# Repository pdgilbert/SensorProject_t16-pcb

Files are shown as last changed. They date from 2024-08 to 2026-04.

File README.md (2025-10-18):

# SensorProject_t16-pcb
Connect multiple temperature sensors to an analog digital converter.

##  Status: Working Prototype.

## Summary

Kicad PCB design to connect multiple (up to 16) thermistor temperature sensors to an ads1115 with I2C
output to connect to an MCU. Connectors are  2-pin JST XH_B2B-XH-A, as commonly used on NTC 10K 3950 sensors.
These sensors are inexpensive and easily available in lengths up to 3m. 
Measurements are broadcast with LoRa.

Software for this hardware is in repository https://github.com/pdgilbert/SensorProject_t16.
The overall project, recording station, etc., 
is described in repository https://github.com/pdgilbert/SensorProject.

The `.png` and `jpg` files are produced from kicad in the `3D Viewer`  with `File > Export Current View as ...`.
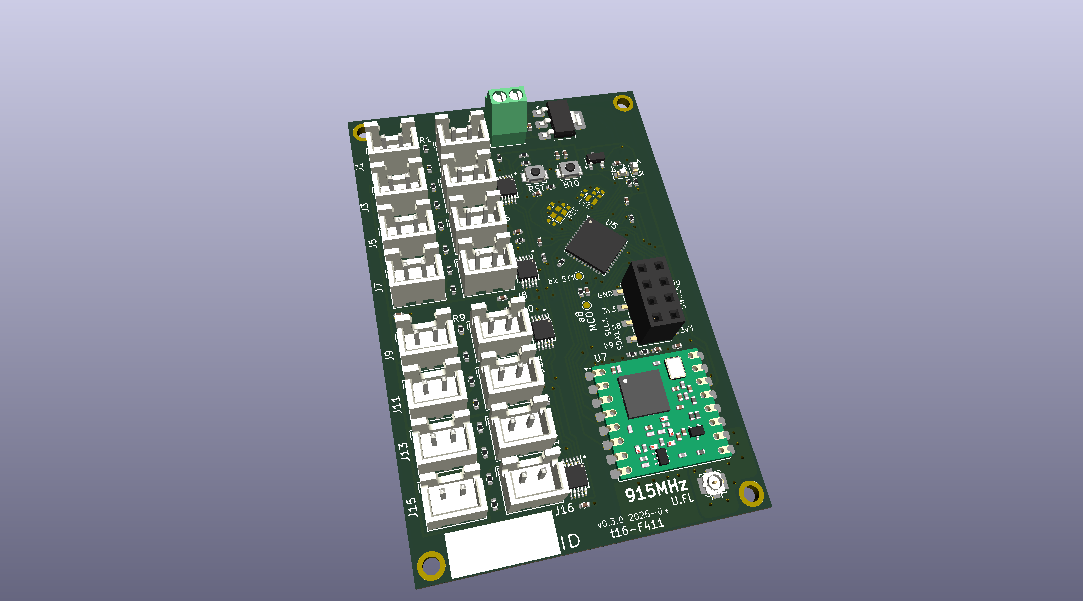
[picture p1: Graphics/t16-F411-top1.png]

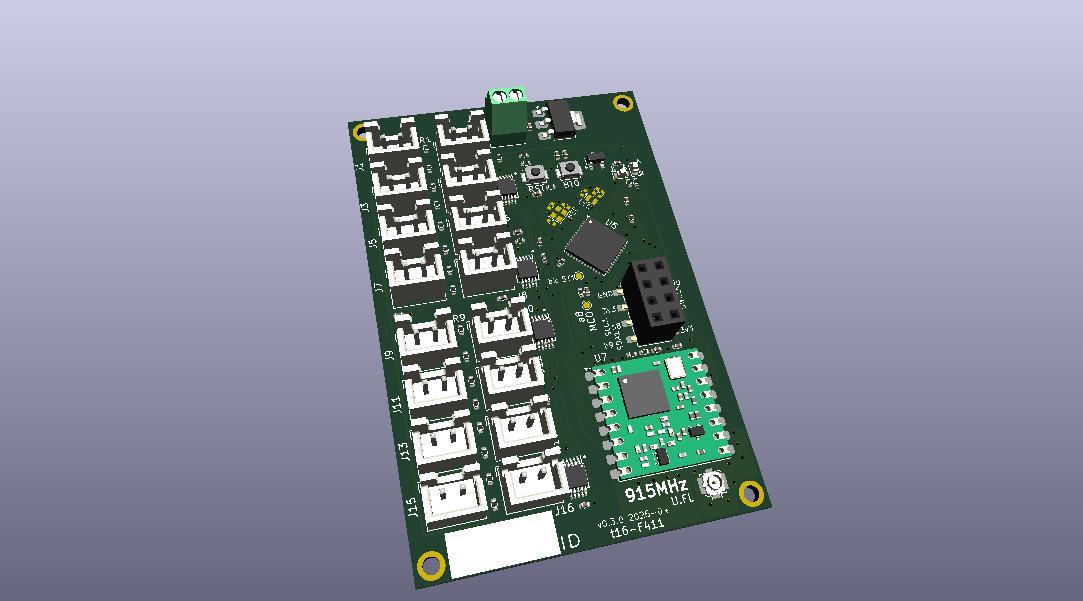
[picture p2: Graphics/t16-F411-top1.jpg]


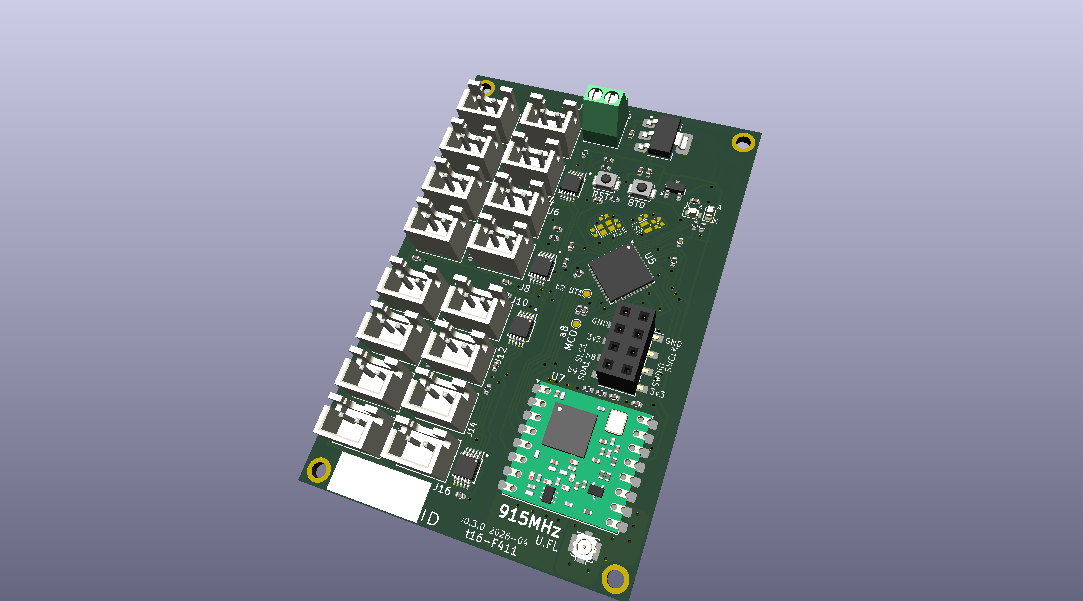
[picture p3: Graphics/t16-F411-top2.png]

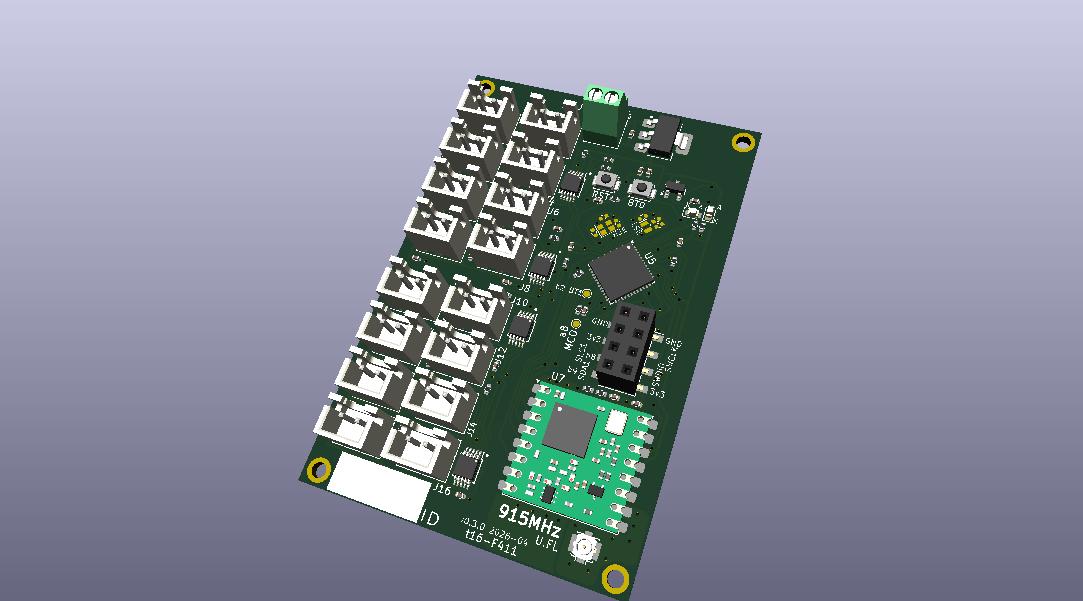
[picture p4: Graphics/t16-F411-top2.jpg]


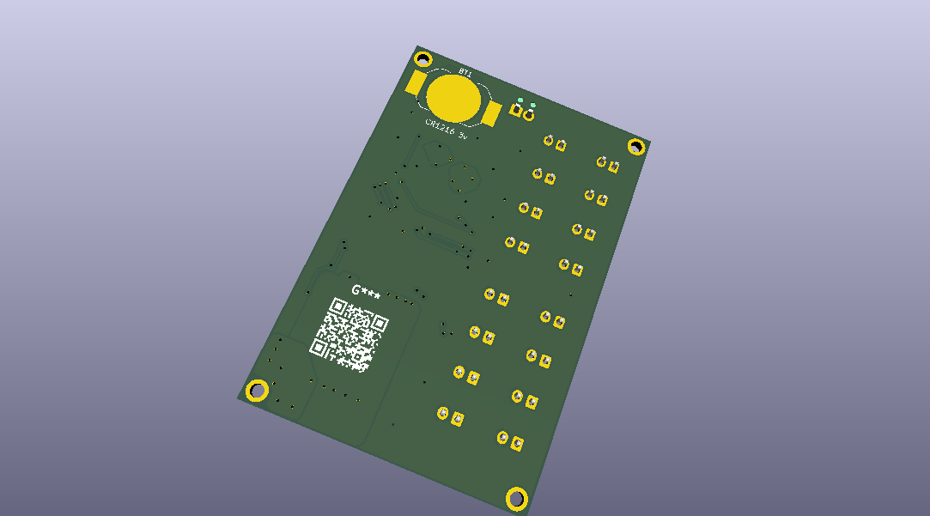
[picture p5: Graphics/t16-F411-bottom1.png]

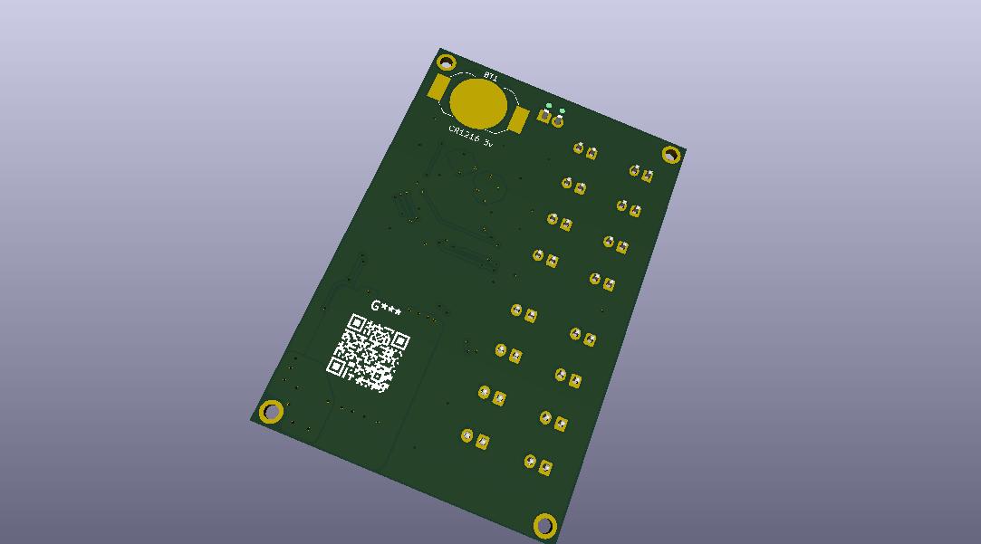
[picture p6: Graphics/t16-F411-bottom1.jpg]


See also file ProjectNotes.txt for additional hardware details.

## History

To see tags and tag messages use  git tag -n 

 - Version 0.2.2 2025-09 includes an stm32f411 MCU. It has an unshielded LoRa module RFM95W.
   It works with no necessary hardware adjustments. Two minor fixes to the BOM are added.
   (The HSE, LSE and RTC are still untested.)

 - Version 0.2.0 2025-05 includes an stm32f411 MCU. It has an unshielded LoRa module RFM95W.
   It needs some hardware re-adjustment to work.

 - Version 0.1.1 2025-01 has pull up resistors added but has not been manufactured/tested.

 - Version 0.1.0 2024-05 needs manual addition of pull up resistors on the I2C lines. 
   With this modification it works with `blackpill` `stm32f401` or `stm32f411` inserted.
   This versin has no LoRa module.

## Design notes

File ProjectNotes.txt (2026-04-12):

grep "/////////////// " ProjectNotes.txt   # for section index

////////////////////////////////////////////////////////////////////////////////
///////////////     General Notes
////////////////////////////////////////////////////////////////////////////////

(See also file `README.md`.)

The 16 JST 2-pin connectors are a size used by many NTC suppliers. 
The NTC sensors are easily available and inexpensive.

The PCB board is 48.1mm by 70.8mm (previously 48.11mm by 70.83mm), which fits (tightly) in a standard NA electric outlet hole. 
This allows for a standard outlet faceplate cover. The board needs to be supplied by low voltage (5v).
An outlet box is not a good option because of the number of sensor wires, but a low voltage single gang 
wall plate with no back, as often used for audio or TV cable, is a good option.

The mounting hole centers are 43.5mm apart in x direction and 66.5 mm in y direction.

In addition to the JST connectors on the analog digital converter (adc) and the LoRa module, the board has 
  - 4 pins on an 8 pin header to connect a ST-link programming dongle.
  - 4 pins on an 8 pin header to connect ssd display on I2C1.
  - a red led indicating when it is powered up.
  - a blue led on pin PC13 which can be programmed to turn on and off.
  - a 25 MHz crystal for the high speed external (HSE) oscillator. (still untested)
  - a 32.768 kHz crystal for the low speed external (LSE) oscillator. (still untested)
  - a coin cell battery holder to supply the real time clock (RTC). (still untested)
  
The HSE, LSE, and RTC are not used by current software but are on the board for future possibilities.
They can be marked do not populate (DNP) to reduce cost.

////////////////////////////////////////////////////////////////////////////////
///////////////            To Do
////////////////////////////////////////////////////////////////////////////////
- Report footprint BUG AMS1117 regulator tab should connect to output not gnd! Requires changing pin 4 GND -> VO
- The crystals/capacitors need testing and may need adjustment. 
- Consider STM32WLE5CCU6 version of MCU with built in LoRa (but need eh1 Rust crate).
    https://www.st.com/en/microcontrollers-microprocessors/stm32wl-series.html
- Consider different cheaper radio options?
- Need LoRa software and radio update.
- The radio needs more testing. 

- 5v J20 connector is a bit fragile. Consider something more robust.
- red led is still pretty bright.

- Consider power led blink off on reset?
- Consider reverse-polarity-protection
      https://electronics.stackexchange.com/questions/665044/which-reverse-polarity-protection-is-better-and-why  

- Need to check clock sensitivity to power suppy.
- Consider possible compensation in temperature calculation with low voltage supply?

-testing:
  - Check if RTC works.
  - Check what happens to RTC when VDD is gone and so NRST goes low.
  - Check HSE and LSE oscillating.

- learn spice.
  
//////////////////////// Sensitivity to Power Suppy

The regulator needs at least 4.3v supply on the J20 connector. Testing has been mostly done with a
5v suppy.  If a 3.2v battery is used to supply the regulator (instead of 5v) then the system boots
and the radio transmits, however the temperature readings are high by nearly 10C.

See below  `revision history and notes` for more details on temperature sensitivity to power suppy.

////////////////////////////////////////////////////////////////////////////////
///////////////            LSE and HSE oscillators
////////////////////////////////////////////////////////////////////////////////

Current software does not require RTC battery, LSE or HSE oscillators. 
LSE and HSE are experimentation for future possibilities.

Regarding Master Clock Output on pins see 
https://community.st.com/t5/stm32-mcus/how-can-i-output-a-clock-signal-to-the-stm32-s-mco-pin/ta-p/588222
and
https://aticleworld.com/stm32h573-mco-clock-output-configuration/

From the datasheet, for UFQFPN48 chip, MCO_1 is on pa8 pin 29. 
MCO_2 requires a 64 pin package to get pc9 so some diagnostics are not available.

///  See ProjectAlternateParts.txt re alternative parts and especially xtal calculations

////////////////////////////////////////////////////////////////////////////////
/////////////////////  RFM95  LoRa radio
////////////////////////////////////////////////////////////////////////////////

Reset pin has internal pull-up.  Do not hold low for long. Current code does not attempt reset.
See  https://www.mouser.ca/datasheet/2/975/1463993415RFM95_96_97_98W-1858106.pdf
"A manual reset of the RFM95/96/97/98(W) is possible even for applications in which VDD cannot
be physically disconnected. Pin 7 should be pulled low for a hundred microseconds, 
and then released. The user should then wait for 5 ms before using the chip."

////////////////////////////////////////////////////////////////////////////////
///////////////     alternate  parts
////////////////////////////////////////////////////////////////////////////////

- See also file ProjectAlternateParts.txt for (very disorganized) notes on alternate parts.

////////////////////////////////////////////////////////////////////////////////
///////////////     battery pad
////////////////////////////////////////////////////////////////////////////////

See https://electronics.stackexchange.com/questions/226967/coin-cell-battery-retainer-problems-and-best-practices
1. Use contact made for this purpose, eg Keystone.  This ... works and allows a lot of routing flexibility beneath the battery.
2. Use ENIG surface finish for the bottom pad.

////////////////////////////////////////////////////////////////////////////////
///////////////     tags and versions
////////////////////////////////////////////////////////////////////////////////

See README.md  History section.

To see tags and tag messages use  git tag -n 
 
////////////////////////////////////////////////////////////////////////////////
///////////////     revision history and notes
////////////////////////////////////////////////////////////////////////////////

///////////////  v0.2.2 2025-09 prototype notes

- includes an STM32F411CEU6 MCU. 
- has a LoRa module HopeRF  RFM95W-915S2  with no shield.
- has a U.FL (IPex 1) socket to attach antenna.

- status: prototype works with no hardware changes, but see below. 
          The necessary BOM changes as below are incorporated in the git version tagged `v0.2.2`.

- manufacturering errors/fixes/clarifications
   - Question re paste on battery pad. Should indicate no paste on battery pad, and ENIG. 
   - Fixed. BOM  had  Hong Cheng HC-PM254-5.0H-2x8PS which has 16 pins (8 pins per row, not 8 pins total)
      Should be Hong Cheng HC-PM254-5.0H-2x4PS-02A  https://www.lcsc.com/product-detail/C42163132.html
      Note also, footprint should work but could be improved to match recommended.
   - Done. Change the part# for UF.L. Footprint was for the gold part and silver was order.
     (The wrong footprint worked but engineering complained that the extra pad was not connecting.)
     The footpint for HRS part silver plated U.FL-R-SMT-1(60) is slightly different from 
     gold plated part U.FL-R-SMT-K(800). Gold has a 3rd ground connect pad opposite the signal pad.
     See  https://www.hirose.com/en/product/document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 
   - KF128-2.54-2P has no positioning pins but footprint has holes. 
     Yes, it is ok to ignore the positioning holes and solder as is.
   
- testing notes with v0.2.2. (Test files in crate SensorProject_t16  examples/ and src/bin/
    (5v supply actually shows 5.21v on measurement dongle and 5.14v on voltmeter.)
    - blink_default runs. Timer good on dongle and 5v supply. 
    - blink_hsi16   runs. Timer good on dongle and 5v supply.
    - blink_hse     fails. Software bug. Run time error `assertion failed: clk.raw() % FREQ == 0`.
    - text_i2c  runs (needs semihosting) using both 128x32 and 128x64 displays.
    - lora_spi_send runs on dongle and 5v. 5v supply draws 20 to 30 mA.

    - t16-f411 main bin  runs on dongle and 5v supply, with and without display. 
      With the display, the 5v supply draws 20 to 30 mA with about 140 mA spike on startup.
      Power usage is similiar without the display.
    - wire antenna on U.FL is as good as the spring coil antenna, possibly better.
    
    - measured temperature is sensitive to voltage supplied to the sensors. 
      At 30 mA the 3.3v AMS1117 regulator should be ok to about 40v supply, but the regulator
      might become noticably warm. Testing has mostly been done with 5v supplied to the AMS1117, 
      but 12v supply is also reported below.
      The AMS1117 needs dropout of 1v, so at least 4.3v supply to give 3.3v to the sensors. 
      The STlink dongle does not use the AMS1117. It supplies 3.3v directly, bypassing the AMS1117.
      If many sensors are connected then the STlink regulator may not supply proper voltage.
      Following testing was done with the equivalent of 4 sensors connected.
        J1 has NTC at room temperature (which changed during testing).
        J2 has  10K resistor connected, which should measure 25 C.
        J3 has  33K resistor connected, which should measure 0.2 C.
        J4 has 100K resistor connected, which should measure -19 C.
        J5 and others have nothing connected.

      It is also possible to power with a LFePo 3.2v battery connected directly to GND and 3v3,
      for example, using the STlink socket. Measurements below show how this affects the measurement.

      5v     XX< J1: 20.1 J2: 23.5 J3: -2.5 J4:-16.2   J5:-25.1  thru AMS1117
      STlink XX< J1: 20.7 J2: 23.5 J3: -2.5 J4:-16.2   J5:-25.1  direct  @3.2+v
      12v    XX< J1: 18.5 J2: 23.4 J3: -2.6 J4:-16.3   J5:-25.2  thru AMS1117
      LFePo  XX< J1: 21.1 J2: 24.8 J3:  0.5 J4:-13.8   J5:-22.4  direct  @3.2+v
      LFePo  XX< J1: 22.1 J2: 25.5 J3:  0.6 J4:-12.5   J5:-21.0  direct  @3.15v
      LFePo  XX< J1: 22.6 J2: 26.2 J3:  1.7 J4:-11.2   J5:-19.6  direct  @2.97v

      Note that the software calculation of the temperature from measured voltage can be improved,
      but does need to assume an adequate stable supply.

///////////////  v0.2.0 2025-05 prototype notes

- includes an STM32F411CEU6 MCU. 
- has a LoRa module HopeRF  RFM95W-915S2  with no shield.
- has a hole to solder on spring coil antenna.

- status: works to measure and transmit. I2c for ssd is on wrong pin, so no display. Tab on regulator is
wrong (on ground and should be on output voltage) and has to be cut.

- testing notes with v0.2.0. (Test files in crate SensorProject_t16  examples/ and src/bin/
    - blink[_hsi] runs.     0.02 A  with 5v input  ( 0.04A with st-link still attached but not powered)
    - blink_impl runs.      ditto
    - text_i2c   fails      init() error BusWriteError because sda1 mistakenly wired to pb6 on pin 42
    - lora_spi_send runs.   0.02 A  with 5v input  ( ditto )
    - measured temperature is sensitive to good supply voltage (see below).

- Temperature values for different power sources (testing with v0.2.0 2025-05):
    fixed resistors :                              J1: 10k  J2: 33k  J3: 100k    J4: sensor 
        should give temperature:                   J1: 25C  J2: 0.2C J3: -19C     J4: ~22-24C

    power by programming dongle                    J1: 26.9 J2:  2.7 J3:-10.1    J4: 24.5
    power by programming dongle                    J1: 25.4 J2:  0.3 J3:-12.8    J4: 23.0
    power by programming dongle                    J1: 25.9 J2:  1.2 J3:-11.8    J4: 23.6 

    power by 3.2v thru regulator                   J1: 43.2 J2: 27.7 J3: 19.5    J4: 41.8
    power by 3.?v thru 3v I2Cx                     J1: 28.5 J2:  5.2 J3: -7.1    J4: 26.8
    power by 3.0v (weak LiFePo bat) thru 3v I2Cx   J1: 31.3 J2:  9.5 J3: -2.1    J4: 29.8
    power by 3.7v (weak USB bat) thru regulator    J1: 23.6 J2: -2.3 J3:-16.0    J4: 21.8 but timing is fast

    power by 5v USB charger thru regulator         J1: 23.7 J2: -2.2 J3:-15.9    J4: 21.5 
    power by 5v USB charger thru regulator         J1: 23.6 J2: -2.3 J3:-16.0    J4: 21.7 
    power by 5v USB charger thru regulator         J1: 23.7 J2: -2.3 J3:-16.0    J4: 21.0 
    power by 5v USB charger thru regulator         J1: 23.7 J2: -2.3 J3:-16.0    J4: 21.6

    power by 5v wall supply thru regulator         J1: 23.7 J2: -2.3 J3:-16.0    J4: 19.3
    power by 5v wall supply thru regulator         J1: 23.7 J2: -2.3 J3:-16.0    J4: 19.3

- errors/fixes (Done indicates the change should be in the next release.):
  - Done (but then switched to smaller footprint). Get correct footprint L1 for MLZ1608N2R2LT000.
         (See also https://gitlab.com/kicad/libraries/kicad-footprint-generator/-/merge_requests/1797 )
  - Done. AMS1117 regulator tab should connect to output not gnd! BEWARE require symbol edit pin 4 GND -> VO
             and watch it does not reset as updating symbol may mess this up. REPORT SYMBOL BUG? maybe both ? and ?_tab2
  - Done. I2C2 is used for ads bus but is labelled 1 in schematics.
  - Done. I2C for ssd is mistakenly labelled scl2, sda2. Closer to I2C1, but still wrong.  
          v0.2.0 2025-0 has wrong pin for sda1. It has b6 on pin 42 but needs b9 (pin 46 UFQFPN48).
  - Done. consider labelling sda1 as pin b?, etc.
  - Done. pull-ups on ssd bus (mistakenly sda2 and scl2).
  - Done. label bt0 and nrst vs sw1 and sw2. And check they work.
  - Done. add label for battery type CR1216 3v
  - Done. switch antenna hole for U.FL-R-SMT-1 (ipex 1). 
          Added zone GND_ANT on RFM pin10 since it is closest to ant pin, but there is no documention about 
          which gnd pin to use, or even suggesting analog and digital grd parts of RFM are separated.
  - Done. label MCO as pin b? (MCO2 not possible with UFQFPN48 package).
  - Done. (See below.) check if it works with 3.2v through regulator.
  - Done. check in rfm95 doc https://cdn.sparkfun.com/assets/learn_tutorials/8/0/4/RFM95_96_97_98W.pdf
  - Done. cleanup and recheck BOM.
  - Done. check question about led orientatins. Add indicators.
          For BT1, no solder paste on the center big pad added to fab layer notes. 
  - Done. reduce led brightness. Changed MfgPart and adjusted resistors.
  - Done. Replaced ssd and st-link connections with 2x4 smt pinsocket. (stlink plug clearance for larger ssd. & low profile? 2x4 smt?)
  - Done. make boot1 pin 20 available to pull high. (Shared pin, if boot0 is high it is read at boot then available for other function?)
          (see notes https://community.st.com/t5/stm32-mcus-products/quadspi-and-boot1-with-stm32f446ret6/m-p/786873)
           https://deepbluembedded.com/stm32-boot-modes-stm32-boot0-boot1-pins/
  - Done. fab layer red led D1 indicates 2.65Vf. Should be 1.8Vf. (Blue is  2.65Vf.)
  - Done. make J18 (MCO) a test point pad rather than hole.

-improvements:
  - Done. Switch to smaller footprints for R, C, L, and leds.
  - Done. radio on same side as MCU.
  - Done. mv R23 and R25 to same side as MCU and radio and eliminate PTH in MCU area.

///////////////  version 0.1.1 2025-01 

- has pull up resistors added but was not manufactured/tested.

///////////////  v0.1.0 2024-05 

-This version has no LoRa module.

-It has pinsockets for a blackpill module.

-needs manual addition of pull up resistors on the I2C lines. 
   With this modification it works with `blackpill stm32f401` or `blackpill stm32f411` inserted.

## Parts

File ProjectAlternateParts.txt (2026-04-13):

To see the current specification the BOM .csv  can be imported to Excel or LibreOffice Calc or
displays nicely with
         column -s ";" -t <  outputs/BOM.csv | less -#2 -N -S
This assumes ; has been set as field separator. Otherwise "," in some fields causes problems
Helps to set range delimiter to -
( -N Don't use line numbers. -S Chop (truncate) long lines rather than wrapping. )

///////////////////// Caps  C_0402_1005Metric  Unpolarized capacitor

10pF C0G, NP0, +/- 0.1pF    TCC0402COG100K500AT
4pF C0G, NP0, +/- 0.1pF     GCM1555C1H4R0CA16D

100nF (= 0.1uF)             Yageo  CC0402KRX7R7BB104  CL05B104KO5NNNC

1uF                            CL05A105KP5NNNC
4.7uF                          CL05A475MQ5NRNC
10uF

///////////////////// Resisters   R_0402_1005Metric

10k 1%           CRCW040210K0FKED
715 1%           CRCW0402715RFKED
280 1%           RC0402FR-07280RL
0                RC0402FR-070RL
634  1%          ERJ2RKF6340X

///////////////////// Antenna

  See specific antenna notes further below.
  Also see 
    https://www.youtube.com/@Mobilefish  tutorial 47 and others
    https://www.youtube.com/watch?v=ZVo2RkBS14o  compares pcb and ceramic

    https://github.com/FabienFerrero/UCA_Board
    https://github.com/FabienFerrero/UCA21
    https://github.com/FabienFerrero/Antenna_Radiation_Measurement
    and other https://github.com/FabienFerrero/   repositories?

/////////////////////  Rome connectors
- J18, J19,  1x20_P2.54mm_Vertical      Female Header 2.54mm 180°Vertical Single row 20 Circuits(DIP)
     TXGA FFH25405-S20S1001K6K  or  JILN 22850120ANG1SYA01 or ...

- J20   1x02_P2.54mm_Horizontal   2 Screw horz TerminalBlock
  Phoenix_MPT-0,5-2-2.54_1x02_P2.54mm_Horizontal"  or Cixi Kefa Elec	KF128-2.54-2P	or ...
https://www.lcsc.com/datasheet/lcsc_datasheet_2303171000_Cixi-Kefa-Elec-KF128-2-54-2P_C474920.pdf

/////////////////////  Resistors, Capacitors and some connectors

- surface mount JST connectors not available in 2 connector. It is available for 3p and more.
  through hole is JST part XH_B2B-XH-A
  BM02B-XASS-TF(LF)(SN) is SMT but is XA connector, not sure it fits XH plugs
    probably not according to 
   https://www.mattmillman.com/info/crimpconnectors/common-jst-connector-types/#paxa

//// PCBWay  has supplied
Samsung	CL10A105KA8NNNC	Unpolarized capacitor	1µF
Samsung	CL10A475KP8NNNC	Unpolarized capacitor	4.7µF
Samsung	CL10B104KB8NNNC	Unpolarized capacitor	0.1µF
Samsung	CL10C100JB8NNNC	Unpolarized capacitor	10pF C0G, NP0, +/- 0.1pF
TDK Corp    CGA3E2C0G1H040CT0Y0N	Unpolarized capacitor	4pF C0G, NP0, +/- 0.1pF
Samsung	CL10B104KB8NNNC	Unpolarized capacitor	100nF

Panasonic	ERJ3EKF6980V	Resistor, US symbol	698
Yageo	RC0603FR-07274RL	Resistor, US symbol	274
Yageo	RC0603FR-070RL	Resistor, US symbol	0
Yageo	RC0603FR-07634RL	Resistor, US symbol	634  1%
Vishay	CRCW060310K0FKEA	Resistor, US symbol	10k 1%

JILN	22850104ANG1SYA01	PinSocket header 1x04  4P
Cixi Kefa Elec	KF128-2.54-2P	Generic screw terminal, 01x02
JILN	22850202ANG1SYA01	PinSocket header 2x02  4P
JST	B2B-XH-A	Connector JST_B2B-XH-A_1x02

/////////////////////  LoRa

NiceRF  LoRa1276-C1-915 is sheilded pin compatible replacement for RFM95W-915S2 (both using Semtech RF transceiver chip SX1276)
Also posibly hpdteks hpd13 module. 
See https://www.rocketscream.com/blog/2017/08/21/the-sx1276-modules-shootout-hoperfs-rfm95w-vs-nicerfs-lora1276-c1-vs-hpdteks-hpd13/

/////////////////////  Antenna

///////// socket
 U.FL=IPEX1.  IPEX4 is smaller.

///////// ceramic chip antennas 
Even thought the chip is small these seem to require a large area of the pcb for ground ...

 https://electronics.stackexchange.com/questions/243341/how-does-a-chip-antenna-work
 https://pcbartists.com/design/rf/chip-antenna-pcb-layout-bluetooth-wifi/

Specified subject to finding good footprint. Temp using coilcraft_MA5532-AE_RFID which is about right size:

//Other Antennas  

Unictron Technologies Corporation AA066   (digikey  H2U646MHLQ0200)
https://www.unictron.com/wireless-communications/wp-content/uploads/2021/04/AA066.pdf
$1.10  Gain 0.9dBi 2W  10x3.2x0.5 mm looks attractive but footprint landing 
pattern has restricted zone that gives a fairly big footprint (23x15mm).

Unictron Technologies Corporation   AA702 which is 915MHz, smaller and weaker,
 gain 0.8 2W  5.0 x 3.0 x 0.5 but digikey shows it H2U64U1H2C0200 but NOT 915MHx.
 and 
Unictron Technologies Corporation  H2U646MHLQ0200
https://www.digikey.com/en/products/detail/unictron-technologies-corporation/H2U646MHLQ0200/9921490
$1.10  Gain 0.9dBi 2W  10x3..2x0.5
have not found another source. Digikey has the evaluation board with 915!

Wurth 7488910915  https://www.digikey.com/en/products/detail/w%C3%BCrth-elektronik/7488910915/12726548
$1.24 Gain 0.5dBi

Taoglas ILA.01 https://www.digikey.com/en/products/detail/taoglas-limited/ILA-01/2332707
$14.17 Gain 1dBi max 5W
and also Taoglas DBP.915.V.A.30

Kyocera M620720
 https://www.kyocera-avx.com/product/ism-868-915-mhz-embedded-ceramic-antenna-m620720/
 https://www.digikey.ca/en/products/detail/kyocera-avx/M620720/6072490
$4.61  Gain 0.75 dBi  6.00 x 2.00 x 1.08  see datasheet p19 re glue
	
Johanson Technology Inc.
https://www.digikey.com/en/products/detail/johanson-technology-inc/0915AT43A0026001E/2137136
$1.54  Gain -1dBi 2 W
7x2mm chip but footprint with ground plan is 42x26mm
https://www.johansontechnology.com/products/antennas/rf-antennas/0915at43a0026001e/
https://www.johansontechnology.com/docs/4410/Antenna-0915AT43A0026001E.pdf

/////////////////////  regulator

https://www.alldatasheet.com/html-pdf/49118/ADMOS/AMS1117/519/4/AMS1117.html
http://www.advanced-monolithic.com/pdf/ds1117.pdf
https://electronics.stackexchange.com/questions/665044/which-reverse-polarity-protection-is-better-and-why

/////////////////////  leds
Resistance calculator:
https://www.digikey.cn/en/resources/conversion-calculators/conversion-calculator-led-series-resistor

blue very common: 2mA  2.65Vf  => 280 ohm resistor

blue:   Yongyu Photoelectric  yy0603bl-nn1s0-t2ar4  2.6~3.1v forward  0603 (1608 metric) 5ma 34~100mcd
                              yy0603bl-nz1s0-t2ar4 
                              yy0603bl-nn1s2-t2ar4            => 100 ohm resistor

blue:   Kingbright  APT1608LVBC/D        2mA  2.65Vf        => 280 ohm resistor
                or  APTD1608LVBC/D   APTD is slightly higher than APT and
                or  APTD1608LQBC/D   all have slightly different brightness.
                or  APHD1608LVBC/

red very common: 2mA  1.8Vf  => 715 ohm resistor

red:  (power led - consider Do Not Populate)
   Yongyu Photoelectric  yy0603re-nn1s0-t2ar4  1.8~2.3v forward  0603 (1608 metric) 5ma 34~100mcd
                         yy0603re-rn1s0-t2ar4 
                         yy0603re-rn2s1-t2ar4            => 400 ohm resistor
                         yy0603re-nn2s0-t2ar4 
                         yy0603re-nn3s0-t2ar4 

red:  Kingbright   APT1608LSECK/J3-PRV       2mA  1.8Vf     => 715 ohm resistor
            or  ...

/////////////////////  MCU 

Reference/Compare
   https://www.pcbway.com/project/shareproject/10_channel_NTC_thermistor_based_temperature_logger_b1c5cdfe.html
   https://stm32world.com/wiki/Black_Pill
   https://stm32-base.org/assets/pdf/boards/original-schematic-STM32F411CEU6_WeAct_Black_Pill_V2.0.pdf
   and   https://uglyduck.vajn.icu/STM32_Pills/BlackPill_STM32F411.pdf 
   and   https://www.pcbway.com/project/shareproject/STM32F401CCUx_core_board.html

   AN2606 Application note - STMicroelectronics STM32 microcontroller system memory boot mode Introduction 
   https://community.st.com/ysqtg83639/attachments/ysqtg83639/stm32-mcu-products-forum/28746/1/cd00167594-stm32-microcontroller-system-memory-boot-mode-stmicroelectroni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

   Reference Manual
   https://www.st.com/resource/en/reference_manual/rm0383-stm32f411xce-advanced-armbased-32bit-mcus-stmicroelectronics.pdf

   [not using STM32F401CCUx / UFQFPN48   x- temperture range and packaging
    STMicroelectronics Arm Cortex-M4 MCU, 256KB flash, 64KB RAM, 84 MHz, 1.7-3.6V, 36 GPIO, UFQFPN48

    The STM32F411 is preferred to STM32F401 because of the FPU, more memory, and also because the second generation (g2) 
    xtal drive allows more xtal possibilities and lower power consumption. Prices do not seem to be very different.
   ]

   Datasheet  STM32F411CEU6 / UFQFPN48
   https://www.st.com/resource/en/datasheet/stm32f411ce.pdf
   STMicroelectronics Arm Cortex-M4 MCU+FPU, 125 DMIPS, 512KB Flash, 128KB RAM, USB OTG FS, 11 TIMs, 1 ADC, 13 comm. interfaces
   C = 48/49 pins
   E = 512 Kbytes of flash memory
   U = UFQFPN
   6 = Industrial temperature range, - 40 to 85 °C
   TR = tape and reel / No character = tray or tube

//////////  MCU  xtals

!!! When considering external capacitors use COG NPO 1% types to minimize the impact of capacitance change over temperature.

Application Note  AN2867
Guidelines for oscillator design on STM8AF/AL/S and STM32 MCUs/MPUs
https://www.st.com/resource/en/application_note/cd00221665-oscillator-design-guide-for-stm8af-al-s-stm32-mcus-and-mpus-stmicroelectronics.pdf

(Summary at 
https://ecsxtal.com/considerations-when-designing-crystals-into-stm32-microcontrollers/  is helpful.)
https://community.nxp.com/t5/LPC-FAQs/How-to-calculate-the-value-of-crystal-load-capacitors/m-p/464589
https://electronics.stackexchange.com/questions/673522/how-do-you-design-a-crystal-oscillator-circuit-for-stm32f4-mcus

Notes from  AN2867

- p23 section 4  Guidelines to select a suitable crystal and external components

- From Fig 12, p23 discussing LSE but seems to apply to HSE too:
   High load-capacitance (such as 12.5 pF) requires more power to drive the oscillation. 
   Low power designs consequently needs relatively small load capacitance. 
   Big load capacitance resonators have a much smaller pullabilty.
   7pF in in the middle, the largest possilbe with low power drive and reasonably good pullabilty.

- p24 crystals with high ESR have longer startup time. Small crystals tend to have large ESR. 
  Without size constraints choose a crystal with the smallest possible ESR.
  In noisy environments (eg industrial applications) with no power constraints, choose crystals with high
  load capacitance. 

- p25 Table 5 for which MCUs have which LSE oscillators, and thus implication for which crystals work.

- p26 4.2  How to select an STM32-compatible crystal

- p31 which suggests cap values for various crystals  and tips in section 7!

- p10 For startup and stable oscillation of STM32 and STM8 products, the ratio between
the negative resistance of the loop and the crystal maximal equivalent series resistance
(ESR) is needed. It is recommended to have a ratio higher
than 5 for the HSE oscillators, and higher than 3 for the LSE oscillators.

- p13 the ratio between oscillator gain and oscillation loop critical gain cannot just (sic) exceed 1.
  For cristal specified  Gm_crit_max  check for oscillation loop critical crystal gain p13.

Regarding capacitors for crystals see application note AN2867
https://www.st.com/resource/en/application_note/cd00221665-oscillator-design-guide-for-stm8af-al-s-stm32-mcus-and-mpus-stmicroelectronics.pdf
and https://community.st.com/t5/stm32-mcus-products/stm32-f4-crystal-calculation-and-discrepancy-with-nucleo-boards/td-p/607114
and https://community.st.com/t5/stm32-mcus-products/calculate-external-capacitors-cl1-and-cl2-for-crystal-oscillator/td-p/620301

"It's better to measure freq on first PCB release/prototype sample via MCO pin (available on 
PA8 + others depends on device and package size). 
Measuring must be done by counter or by scope with averaging (or in counter mode) to avoid short 
term jitter. And then tune external capacitors accordingly to get nominal crystal frequency.
fmeas > fnom \u2026 increase external capacitors
fmeas < fnom \u2026 decrease external capacitors
"
And regarding measuring on PA8 see
https://community.st.com/t5/missing-articles/how-can-i-output-a-clock-signal-to-the-stm32-s-mco-pin/td-p/49583

Regarding setting RTC and LSE driver medium/low
https://blog.brendans-bits.com/posts/2024/setting-the-stm32-system-clock/

########## # python code to check crystal 

import math

def crit_margin(F, ESR, C0, CL, CS, gm, Vpp) :
   '''
   crit_margin(F, ESR, C0, CL, gm, Vpp)
     where
     F   in Hz is frequency.
     ESR in Ohms is equivalent series resistance of the crystal. 
     C0 in F is the crystal (shunt) capacitance.
     CS in F is the stray capacitance in the board, often assumed about 5 pF. Needs to be measured for best accuracy. 
     Note: If CL < CS then calculated external capacitors have negative value!
     CL in F is the load capacitance that the crystal is design to expect from the board (from CS and C1 and C2). 
     gm in A/V
     Vpp peak-to-peak voltage of oscillator. (which I think would not exceed Vss - Vdd)
   
   '''
   # C1 and C2 assumed equal and called C below. It is calculated from 
   #   CL = CS + C1*C2 / (C1 + C2)   # AN2867 p12
   #   CL = CS + C**2 / 2*C  = CS + C/2
   #    C = C1 = C2 = 2 * (CL - CS)
   C = 2 * (CL - CS)
   print("   Require external capacitors C1 = C2 = ", C)
   
   # (AN2867 p16 3.5.3) check ext resistor
   R_ext = 1.0 / (2.0 * math.pi * F * C)
   print("   Require external resistor R_ext = ", R_ext)
   
   # (AN2867 p14-16) need to check drive level   !!!!!
   
   gm_critical =   4 * (ESR + R_ext) * (2 * math.pi * F)**2 * (C0 + CL)**2  #p16
   gm_critical_no_R_ext = 4 * (ESR ) * (2 * math.pi * F)**2 * (C0 + CL)**2 
   
   gain_margin = gm / gm_critical   
   print("   gm_critical = ", gm_critical, " A/V; gain_margin =", gain_margin)
   
   gain_margin_no_R_ext = gm / gm_critical_no_R_ext   
   print("   gm_critical with no R_ext = ", gm_critical_no_R_ext, " A/V; gain_margin with no R_ext =", gain_margin_no_R_ext)
   
   # drive level (power dissipated by crystal  (AN2867 p14-16)
   Ctot =CL + (CS/2)
   DL = (ESR * (math.pi * F * Ctot)**2 * Vpp**2 ) /2   # No probe. Assuming Vpp =3.2v 
   print("   drive level = ", DL*10**6, " uW must not exceed manuf. spec.")
   
   print("\nNotes")
   print("R_ext is not recommended (=0) if the drive level is lower than specified by the manufacturer.")
   print("Otherwise, R_ext is needed.")
   print("gm should be (much) bigger than gm_critical, so gain margin >> 1")  #AN2867 p16
   print("Use COG NPO 1% capacitor types to minimize the impact of temperature.")
   
   if F > 10**7:  # HSE
      print("F4 HSE resonator needs frequency 4-26 MHz;  g_m(min) = 5mA/V;  G_m_crit_max = 1 mA/V (from AN2867 table 6, p29)")
       
   else:
      print("F411 (generation_2 LSE oscillator  from AN2867 table 5, p25)")
      print("     drive Low   g_m(min)=2.8 uA/V;  G_m_crit_max = 0.56 uA/V")
      print("     drive High  g_m(min)=7.5 uA/V;  G_m_crit_max = 1.5  uA/V")
   
   return()

########## #  check code's calculation
#  Example to check calculation against AN2867 p14. 

>>>crit_margin(F=8.0*10**6,  ESR=80,  C0=7.0*10**-12, CL=10.0*10**-12, CS= 5*10**-12,  gm=25*10**-3)
Require external capacitors C1 = C2 =  1e-11  # 10 pF
Use COG NPO 1% capacitor types to minimize the impact of temperature.
Require external resistor R_ext =  1989.436788648692   # 2K Ohms
gm_critical =  0.006044351471922944  A/V; gain_margin = 4.13609303101074
gm_critical with no R_ext =  0.00023366169984326241  A/V; gain_margin with no R_ext = 106.99228849558877

Notes
Use COG NPO 1% capacitor types to minimize the impact of temperature.
F411 (generation_2 LSE oscillator  from AN2867 table 5, p25)
     drive Low   g_m(min)=2.8 uA/V;  G_m_crit_max = 0.56 uA/V
     drive High  g_m(min)=7.5 uA/V;  G_m_crit_max = 1.5  uA/V

########## # 

//////////////////////////////////////////////////////// 
//////// Low speed oscillator (LSE)  F = 32.768   # kHz 
//////////////////////////////////////////////////////// 

////////  1.6 x 1.0mm

The sweet point for LSE crystals seems to be 7pF  from AN2867 Fig 12 p23). 
This can achieve low power drive requirement and low drift.

On Digikey it is *sometimes* possible to scroll down to substitues and find parametric substitues.
eg: https://www.digikey.ca/en/products/detail/ ... to Wurth 830066431
Otherwise select all atributes other than manufacture specific and "View Similar".

######  Micro Crystal 1.6 x 1.0mm
        CM9V-T1A-32.768KHZ-xPF-20PPM-TA-QC  (4, 6, and 7pF work for F411 in AN2867 p32 table 7. )
    C_0  1.4 pF;  ESR max 90kOhm on table but 75kOhm on datasheet;
C_L 4pF has gmcrit  0.4449 uA/V and works for F401 (g1) in AN2867 p31 table 7 but is not easily available. 
C_L 7pF has gmcrit  1.0768 uA/V and works for F411 (g2) in AN2867 p31 table 7 and is available.

######  Micro Crystal CM9V-T1A-32.768KHZ-7PF-20PPM-TA-QC
https://www.microcrystal.com/fileadmin/Media/Products/32kHz/Datasheet/CM9V-T1A.pdf
drive level 0.5uW max
gm_crit 1.078 uA/V  comes from AN2867 p31 table 7, p32, which also indicated the 7pF version of
this chip is good for F4_g2. The datasheet does not specify gm, or gm_crit, or gain_margin.

Assuming Vpp =3.2v  which is a max with 3.2v supply. (Would be better to measure with an oscillascope.
>>> crit_margin(F=32768.0,  ESR=70*10**3,  C0=1.4*10**-12, CL=7.0*10**-12, CS= 5*10**-12, gm=math.nan, Vpp=3.2) 

  Require external capacitors C1 = C2 =  4.000000000000001e-12   # 4 pF
  Require external resistor R_ext =  1214255.852446711           
  gm_critical =  1.536489948822002e-05  A/V; gain_margin = nan
  gm_critical with no R_ext =  8.374834049822095e-07  A/V; gain_margin with no R_ext = nan
  drive level =  0.3427794888872763  uW must not exceed manuf. spec.
( With Vpp = 3.2v the DL <  0.5uW manuf. spec, so R_ext should be =0.
  With Vpp = 5.0v the DL = 0.836 which exceeds the manuf. spec so an R_ext would be needed.)

Notes
R_ext is not recommended (=0) if the drive level is lower than specified by the manufacturer.
Otherwise, R_ext is needed.
gm should be (much) bigger than gm_critical, so gain margin >> 1
Use COG NPO 1% capacitor types to minimize the impact of temperature.
F411 (generation_2 LSE oscillator  from AN2867 table 5, p25)
     drive Low   g_m(min)=2.8 uA/V;  G_m_crit_max = 0.56 uA/V
     drive High  g_m(min)=7.5 uA/V;  G_m_crit_max = 1.5  uA/V

DID THIS WITH WRONG FREQ (25MHz)25.0*10**6  NOTE BIG DIFFERENCE IN R_ext
crit_margin(F=25.0*10**6,  ESR=70*10**3,  C0=1.4*10**-12, CL=7.0*10**-12, CS= 5*10**-12, gm=math.nan, Vpp=3.2) 
Require external capacitors C1 = C2 =  4.000000000000001e-12   # 4 pF
Require external resistor R_ext =  1591.5494309189532          # 1.6K
gm_critical =  0.49856303946047026  A/V; gain_margin = nan

4pF COG NPO 1% : 
eg Murata Electronics GJM0335C1E4R0WB01D  CAP CER 4PF 25V C0G/NP0 0201
0201 (0603 Metric)  0.024" L x 0.012" W (0.60mm x 0.30mm)

######  Wurth  830066431  IQXC-90   WE-XTAL QUARTZ CRYSTAL 32.7680 K   1.60mm x 1.00mm
https://www.we-online.com/components/products/datasheet/830066431.pdf
drive level 500nW max
>>> crit_margin(F=32768.0,  ESR=90*10**3,  C0=1.2*10**-12, CL=7.0*10**-12, CS= 5*10**-12, gm=math.nan, Vpp=3.2) 

######  TXC  9H03270102  1.6mm x 1mm   CL=6.0
drive level 0.1 uW typ 0.5 uW max
>>> crit_margin(F=32768.0,  ESR=70*10**3,  C0=1.3*10**-12, CL=6.0*10**-12, CS= 5*10**-12, gm=math.nan, Vpp=3.2) 

######  Epson  FC1610AN 32.7680KA-AG5   32.7680KHZ 7PF SMD  90 kOhms
https://support.epson.biz/td/api/doc_check.php?dl=brief_FC1610AN&lang=en
Not listed in AN2867 p31 table 7

######  NDK  narrowed down to NX1610SE 32.768 kHz  specification# STD-MUD-6
NDK crystals did not seem to be very readily available.
https://www.ndk.com/en/products/
https://www.ndk.com/en/products/lineup/crystal-unit/
https://www.ndk.com/images/products/catalog/crystal_e.pdf  
- AN2867 p31 table 7   NDK   NX1610SE 32.768 kHz EXS00A-MU01501 is good for F4.
                       Others, eg  -MU01500, are good for F4_g2, which includes F411 but not F401.  
   NX1610SE 32.768 kHz EXS00A-MU01501  specs from table 7: 
        ESR 60 kOhms max,  C_0 1.55pF,  C_L 6pF, g_mcrit 0.5799 uA/V
However what is available on NDK site
   https://www.ndk.com/en/products/lineup/crystal-unit/NX1610SE.html
  data sheet https://www.ndk.com/en/products/upload/lineup/pdf/NDKX01-00011_en.pdf
 NX1610SE 32.768 kHz  specification# STD-MUD-6  Load capacitance CL 6.0pF;  ESR Max. 60 kOhms ;

######  considering  ECS-.327-7-16-C-TR   ESR=90Kohms, CL=7pF, C0=1.3pF
Part Number/s	          STM32 Series
	    gm (uA/V)	Design Gm_crit-Max	Oscillator Margin	Actual gmcrit (µA/V)	Size	ESR k\u2126	Tolerance (ppm)	CL (pF)	C0	Operating Temp.	Rating	Data-sheet	Inventory
ECS-.327-7-16-C-TR	F4_g2 series / high
	7.50	1.5	7.13	1.0512	1.6 x 1.0mm	90	10	7.0	1.3	-40 ~ +85°C	-	https://ecsxtal.com/store/pdf/ECX-16.pdf	https://dilp.netcomponents.com/cgi-bin/ecsxtal.asp?=1&partnumber1=ECS-.327-7-16-C-TR

## from  ECS DESIGN TOOL https://ecsxtal.com/stm32-mcu-series-lse-32-768khz-crystal-selection-tool/
Part Number/s	           STM32 Series	        gm   Design Gm_ Oscill. Actual gmcrit 	Size	        ESR   Tolerance	CL 	C0	Operating 	Rating	Data-sheet	Inventory
                                               (uA/V) crit-Max	Margin	  (µA/V)	Size	       K Ohms  (ppm)	 pF 	 	 Temp.	        Rating	Data-sheet	Inventory
ECS-.327-4-16R-TR	F4_g1 series / Standard	2.80	0.56	9.10	0.3077487	1.6 x 1.0mm	60	20	4.0	1.5		        -	https://ecsxtal.com/store/pdf/ECX-16R.pdf	https://dilp.netcomponents.com/cgi-bin/ecsxtal.asp?=1&partnumber1=ECS-.327-4-16R-TR
ECS-.327-4-16R-TR	F4_g2 series / high	7.50	1.5	24.37	0.3077487	1.6 x 1.0mm	60	20	4.0	1.5		        -	https://ecsxtal.com/store/pdf/ECX-16R.pdf	https://dilp.netcomponents.com/cgi-bin/ecsxtal.asp?=1&partnumber1=ECS-.327-4-16R-TR
ECS-.327-7-16-C-TR	F4_g2 series / high	7.50	1.5	7.13	1.0512	        1.6 x 1.0mm	90	10	7.0	1.3	-40 ~ +85°C	-	https://ecsxtal.com/store/pdf/ECX-16.pdf	https://dilp.netcomponents.com/cgi-bin/ecsxtal.asp?=1&partnumber1=ECS-.327-7-16-C-TR
ECS-.327-6-16R-TR	F4_g2 series / high	7.50	1.5	13.11	0.5722	        1.6 x 1.0mm	60	20	6.0	1.5	-40 ~ +85°C	-	https://ecsxtal.com/store/pdf/ECX-16R.pdf	https://dilp.netcomponents.com/cgi-bin/ecsxtal.asp?=1&partnumber1=ECS-.327-6-16R-TR
ECS-.327-6-16-TR3	F4_g2 series / high	7.50	1.5	8.08	0.9284	        1.6 x 1.0mm	90	20	6.0	1.3	-40 ~ +85°C	-	https://ecsxtal.com/store/pdf/ECX-16.pdf	https://dilp.netcomponents.com/cgi-bin/ecsxtal.asp?=1&partnumber1=ECS-.327-6-16-TR3

Above results from ECS DESIGN TOOL for gm_critical and Oscill.Margin (=gain_margin) 
compare with no R_ext result below.  (Note uA/V above vs A/V below)

Notes from AN2867 table 5, p25)
     drive Low   g_m(min)=2.8 uA/V;  G_m_crit_max = 0.56 uA/V
     drive High  g_m(min)=7.5 uA/V;  G_m_crit_max = 1.5  uA/V

ECS-.327-4-16R-TR   ** Should have no  R_ext  **
>>> crit_margin(F=32768.0,  ESR=60*10**3,  C0=1.5*10**-12, CL=4.0*10**-12, CS= 0, gm=2.80*10**-6, Vpp=3.2)  # drive Low
  Require external capacitors C1 = C2 =  8e-12
  Require external resistor R_ext =  607127.9262233557
  gm_critical =  3.4217958694061296e-06  A/V; gain_margin = 0.8182837629311752  # gain margin SHOULD BE >> 1  !!
  gm_critical with no R_ext =  3.0774870020301075e-07  A/V; gain_margin with no R_ext = 9.098332497108649

ECS-.327-4-16R-TR    F4_g2 series / high    ** probably  no  R_ext  **
>>> crit_margin(F=32768.0,  ESR=60*10**3,  C0=1.5*10**-12, CL=4.0*10**-12, CS= 0, gm=7.50**-6, Vpp=3.2) # drive High
  Require external capacitors C1 = C2 =  8e-12
  Require external resistor R_ext =  607127.9262233557
  gm_critical =  3.4217958694061296e-06  A/V; gain_margin = 1.6420195438791367  # gain margin ok but not big
  gm_critical with no R_ext =  3.0774870020301075e-07  A/V; gain_margin with no R_ext = 18.257284885438484

ECS-.327-4-16R-TR    F4_g2 series / low   ** with low setting gain margin is good even with R_ext **
>>> crit_margin(F=32768.0,  ESR=60*10**3,  C0=1.5*10**-12, CL=4.0*10**-12, CS= 0, gm=2.80**-6, Vpp=3.2)   # drive Low
  Require external capacitors C1 = C2 =  8e-12
  Require external resistor R_ext =  607127.9262233557
  gm_critical =  3.4217958694061296e-06  A/V; gain_margin = 606.4537896301986
  gm_critical with no R_ext =  3.0774870020301075e-07  A/V; gain_margin with no R_ext = 6743.03765043816

//////////////////////////////////////////////////////// 
//////// High speed oscillator (HSE)  F = 25.0 *10**6  Hz  (25MHz)    4-pin, gnd on 2 & 4   2.0 x 1.6mm or 1.60 x 1.20mm footprint
//////////////////////////////////////////////////////// 

######   Epson  FA-128 25.0000MF20X-K0   2.0 x 1.6mm   10pf
https://support.epson.biz/td/api/doc_check.php?dl=brief_FA-128&lang=en
>>>crit_margin(F=25.0*10**6,  ESR=80,  C0=math.nan, CL=10.0*10**-12, CS= 5*10**-12, gm=math.nan, Vpp=3.2)
Require external capacitors C1 = C2 =  1e-11        # 10pF
Require external resistor R_ext =  636.6197723675814
gm_critical =  nan  A/V; gain_margin = nan
gm_critical with no R_ext =  nan  A/V; gain_margin with no R_ext = nan

Notes
Use COG NPO 1% capacitor types to minimize the impact of temperature.
F4 HSE resonator needs frequency 4-26 MHz;  g_m(min) = 5mA/V;  G_m_crit_max = 1 mA/V (from AN2867 table 6, p29)
()

###### look for SJK  q-crystal.com  referenced in 2.0 x 1.6mm footprint
https://q-crystal.com/home/index/product/eng/MHz-Crystal/f_eng/Crystal-Resonator-List.html

Shenzhen SCTF Electronics	SX1B25.000F0810F30	(25 days digi.ca  )
25 MHz ±10ppm Crystal 8pF 80 Ohms 4-SMD, No Lead   2.0 x 1.6mm 
https://www.sctf-crystal.com/data/upload/admin/20240930/1X-Series-2024-09-30.pdf
CL= 6-20 pF ;  C0=3pF max ; gm=    drive level 10uW typ 100uW max ;
>>>crit_margin(F=25.0*10**6,  ESR=80,  C0=3.0*10**-12, CL=8.0*10**-12, CS= 5*10**-12, gm=math.nan, Vpp=3.2)
Require external capacitors C1 = C2 =  6e-12                      # 6pF
Require external resistor R_ext =  1061.032953945969              # 1.1 K
gm_critical =  0.013626468075504283  A/V; gain_margin = nan
gm_critical with no R_ext =  0.0009553777060254499  A/V; gain_margin with no R_ext = nan

Notes
Use COG NPO 1% capacitor types to minimize the impact of temperature.
F4 HSE resonator needs frequency 4-26 MHz;  g_m(min) = 5mA/V;  G_m_crit_max = 1 mA/V (from AN2867 table 6, p29)

######      KKST 25.000 on blackpill. Cannot find manufactureer.

######   ECS Inc International    2.0 x 1.6mm
#Part Number/s	     Frequency  Series  gm      Gm_crit-Max   Oscillator gmcrit  Size (mm)   ESR   Tol.	 STAB.  CL     C0   Op. Temp	Rating	Data-sheet	Inventory
#                      (MHz)            (mA/V)      (mA/V)       Margin   (mA/V)                   (ppm)  (ppm) (pF)   (pF)
#ECS-250-8-37B2-RWY-TR	25.00	STM32F4	5.00	    1.00	 8.37	 0.597	  2.0 x 1.6   50   15      15	 8     3    -30/85C	-	https://ecsxtal.com/store/pdf/ECX-1637B2.pdf

>>>crit_margin(F=25.0*10**6,  ESR=50,  C0=3.0*10**-12, CL=8.0*10**-12, CS= 5*10**-12, gm=5.0*10**-3, Vpp=3.2)
Require external capacitors C1 = C2 =  6e-12                                    # 6pF
Require external resistor R_ext =  1061.032953945969                            # 1.1 K
gm_critical =  0.01326820143574474  A/V; gain_margin = 0.3768408268606718
gm_critical with no R_ext =  0.0005971110662659061  A/V; gain_margin with no R_ext = 8.373651540689075  !! this is value that compares with manuf. spec above

Notes
Use COG NPO 1% capacitor types to minimize the impact of temperature.
F4 HSE resonator needs frequency 4-26 MHz;  g_m(min) = 5mA/V;  G_m_crit_max = 1 mA/V (from AN2867 table 6, p29)

######   Wurth  IQXC-26  830081609    1.60 x 1.20mm   CHECK FOOTPRINT
 https://www.we-online.com/components/products/datasheet/830081609.pdf
drive level 100uW max     ESR=150max on datasheet, 200 on Digikey
>>> crit_margin(F=25.0*10**6,  ESR=150,  C0=3*10**-12, CL=8.0*10**-12, CS= 5*10**-12, gm=math.nan, Vpp=3.2)

DOES THIS MAKE SENSE??

F4 HSE resonator needs frequency 4-26 MHz;  g_m(min)=5;  G_m_crit_max = 1
Require external capacitors C1 = C2 =  6e-12                                       # 6pF
Require external resistor R_ext =  1061.032953945969                               # 1.1 K
gm_critical =  0.014462423568276551  A/V; gain_margin = nan

Notes
Use COG NPO 1% capacitor types to minimize the impact of temperature.
F4 HSE resonator needs frequency 4-26 MHz;  g_m(min) = 5mA/V;  G_m_crit_max = 1 mA/V (from AN2867 table 6, p29)
F411  drive Low   g_m(min)=2.8 uA/V;  G_m_crit_max = 0.56 uA/V (from AN2867 table 5, p25)
F411  drive High  g_m(min)=7.5 uA/V;  G_m_crit_max = 1.5  uA/V (from AN2867 table 5, p25)

######   IQD Frequency Products   LFXTAL081609    1.60 x 1.20mm
https://www.iqdfrequencyproducts.com/products/datasheets/LFXTAL081609.pdf
 ESR=150 on digikey  200max on datasheet;  drive level  100uW max
>>> crit_margin(F=25.0*10**6,  ESR=150,  C0=7*10**-12, CL=8.0*10**-12, CS= 5*10**-12, gm=math.nan, Vpp=3.2)

Require external capacitors C1 = C2 =  6e-12                                      # 6pF
Require external resistor R_ext =  1061.032953945969                              # 1.1 K
gm_critical =  0.026892936387291105  A/V; gain_margin = nan

Notes
Use COG NPO 1% capacitor types to minimize the impact of temperature.
F4 HSE resonator needs frequency 4-26 MHz;  g_m(min) = 5mA/V;  G_m_crit_max = 1 mA/V (from AN2867 table 6, p29)
F411  drive Low   g_m(min)=2.8 uA/V;  G_m_crit_max = 0.56 uA/V (from AN2867 table 5, p25)
F411  drive High  g_m(min)=7.5 uA/V;  G_m_crit_max = 1.5  uA/V (from AN2867 table 5, p25)

######   ITS Frequency Controls
https://www.iqdfrequencyproducts.com/products/datasheets/LFXTAL081609.pdf

######      25 MHz  NDK_NX1612SA     

########## IoT crystals

# Abracon  https://abracon.com/news/how-critical-is-gm-critical claims much better performance 
with tecknolegy not subject to this calculation (if I understand correctly, which is unlikely)

# Abracon   ABM12W at 25 MHz
crit_margin(F=25.0*10**6,  ESR=80,  C0=2.0*10**-12, CL=4.0*10**-12, gm=5.68*10**-3, Vpp=3.2)
gm_critical =  0.0002842446067513735  A/V; gain_margin = 19.98278899612773
that is gm_critical =  0.284 mA/V but their table shows 5.68  mA/V
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

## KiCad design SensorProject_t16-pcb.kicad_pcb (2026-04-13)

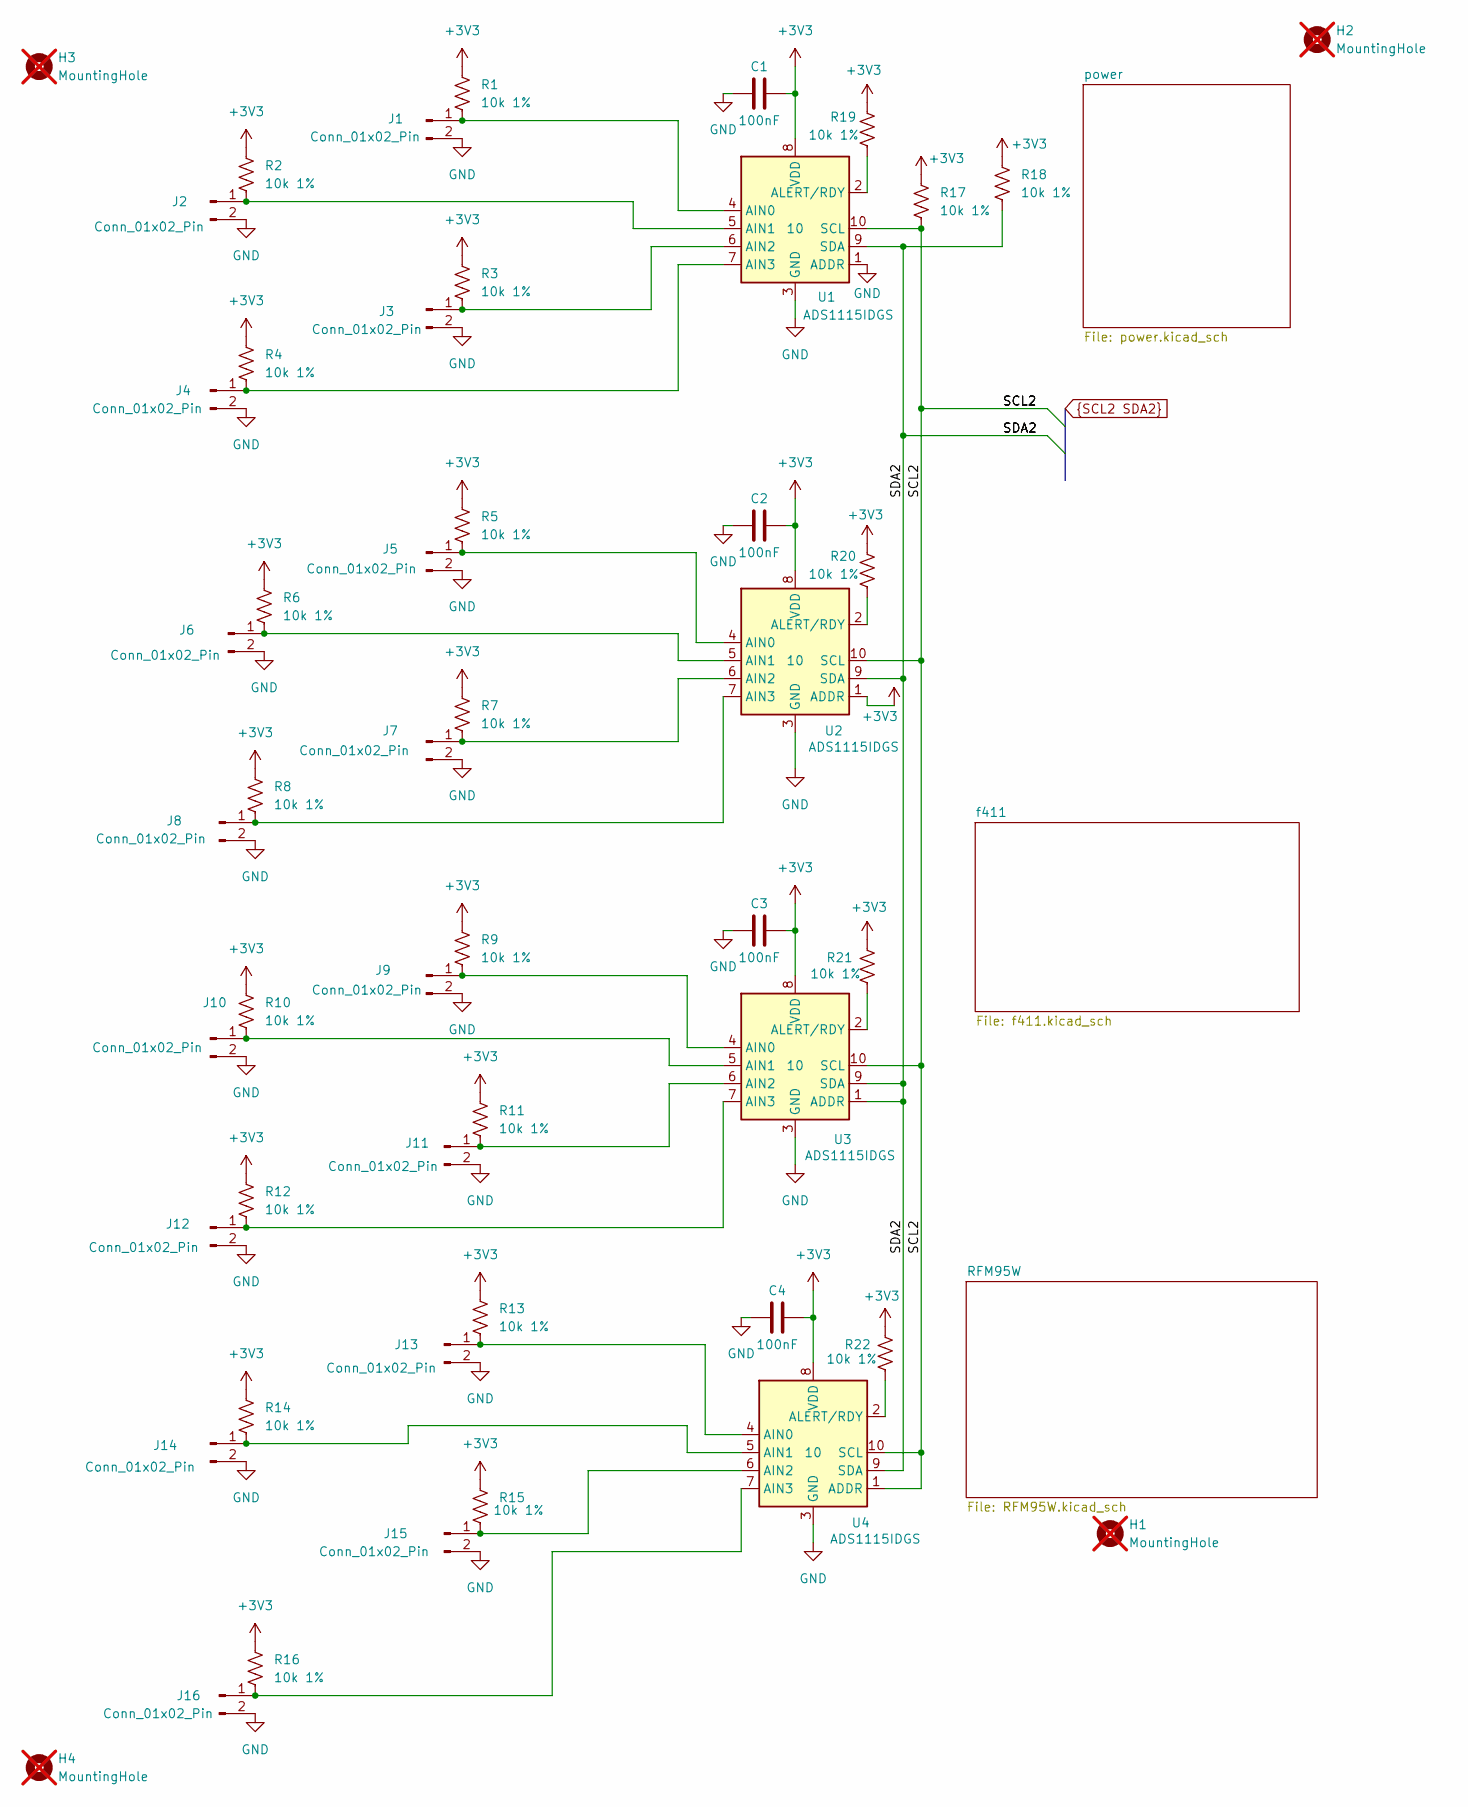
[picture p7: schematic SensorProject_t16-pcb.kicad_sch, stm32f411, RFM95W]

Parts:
C1, C2, C3, C4: 100nF; C_0402_1005Metric
H1, H2, H3, H4: MountingHole; MountingHole_2.2mm_M2_ISO7380_Pad; not fitted
J1, J2, J3, J4, J5, J6, J7, J8, J9, J10, J11, J12, J13, J14, J15, J16: Conn_01x02_Pin; JST_XH_B2B-XH-A_1x02_P2.50mm_Vertical; MfgPart B2B-XH-A
R1, R2, R3, R4, R5, R6, R7, R8, R9, R10, R11, R12, R13, R14, R15, R16, R17, R18, R19, R20, R21, R22: 10k 1%; R_0402_1005Metric
U1, U2, U3, U4: ADS1115IDGS; TSSOP-10_3x3mm_P0.5mm; MfgPart ADS1115IDGS

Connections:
+3V3: C1.1, C2.1, C3.1, C4.1, R1.1, R2.1, R3.1, R4.1, R5.1, R6.1, R7.1, R8.1, R9.1, R10.1, R11.1, R12.1, R13.1, R14.1, R15.1, R16.1, R17.1, R18.1, R19.1, R20.1, R21.1, R22.1, U1.8 (VDD), U2.1 (ADDR), U2.8 (VDD), U3.8 (VDD), U4.8 (VDD); also elsewhere on the board
GND: C1.2, C2.2, C3.2, C4.2, J1.2, J2.2, J3.2, J4.2, J5.2, J6.2, J7.2, J8.2, J9.2, J10.2, J11.2, J12.2, J13.2, J14.2, J15.2, J16.2, U1.1 (ADDR), U1.3 (GND), U2.3 (GND), U3.3 (GND), U4.3 (GND); also elsewhere on the board
unnamed: J1.1, R1.2, U1.4 (AIN0)
unnamed: J2.1, R2.2, U1.5 (AIN1)
unnamed: J3.1, R3.2, U1.6 (AIN2)
unnamed: J4.1, R4.2, U1.7 (AIN3)
unnamed: J5.1, R5.2, U2.4 (AIN0)
unnamed: J6.1, R6.2, U2.5 (AIN1)
unnamed: J7.1, R7.2, U2.6 (AIN2)
unnamed: J8.1, R8.2, U2.7 (AIN3)
unnamed: J9.1, R9.2, U3.4 (AIN0)
unnamed: J10.1, R10.2, U3.5 (AIN1)
unnamed: J11.1, R11.2, U3.6 (AIN2)
unnamed: J12.1, R12.2, U3.7 (AIN3)
unnamed: J13.1, R13.2, U4.4 (AIN0)
unnamed: J14.1, R14.2, U4.5 (AIN1)
unnamed: J15.1, R15.2, U4.6 (AIN2)
unnamed: J16.1, R16.2, U4.7 (AIN3)
unnamed: R19.2, U1.2 (ALERT/RDY)
unnamed: R20.2, U2.2 (ALERT/RDY)
unnamed: R21.2, U3.2 (ALERT/RDY)
unnamed: R22.2, U4.2 (ALERT/RDY)
SCL2: R17.2, U1.10 (SCL), U2.10 (SCL), U3.10 (SCL), U4.1 (ADDR), U4.10 (SCL); also elsewhere on the board
SDA2: R18.2, U1.9 (SDA), U2.9 (SDA), U3.1 (ADDR), U3.9 (SDA), U4.9 (SDA); also elsewhere on the board

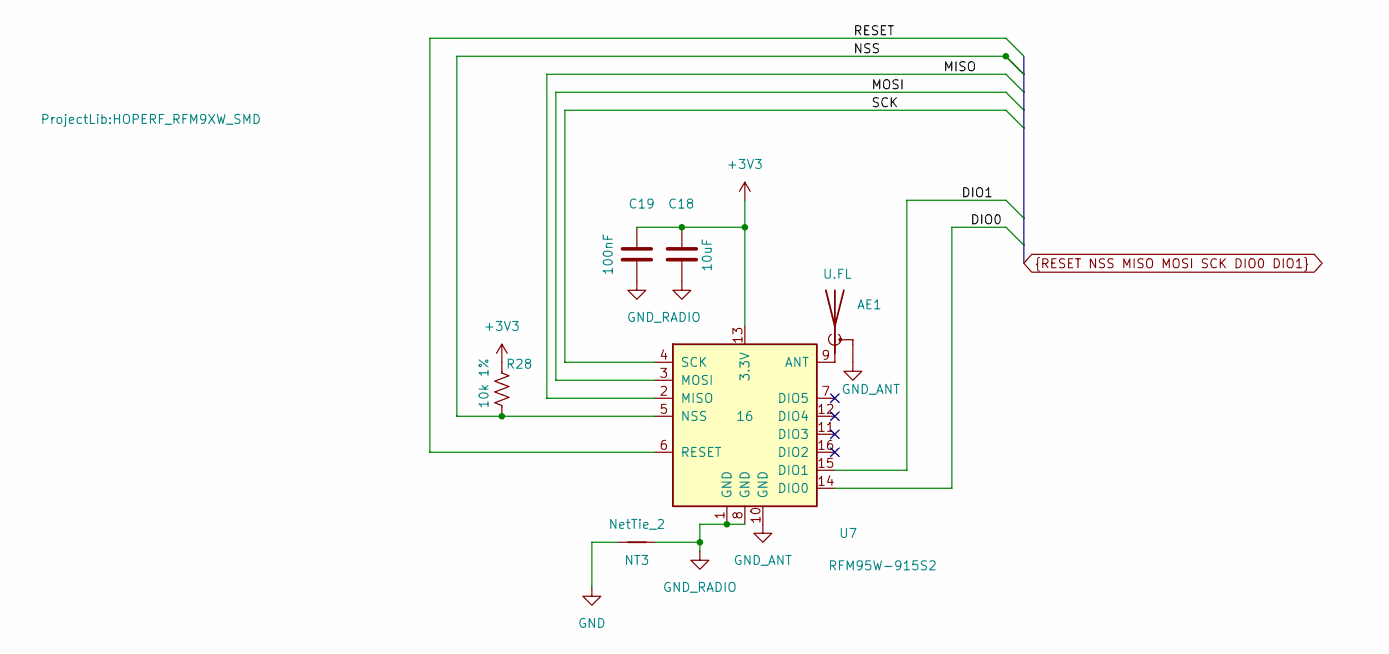
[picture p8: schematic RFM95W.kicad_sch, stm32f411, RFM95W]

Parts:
AE1: U.FL; U.FL_Molex_MCRF_73412-0110_Vertical; MfgPart U.FL-R-SMT-K(800)
C18: 10uF; C_0402_1005Metric
C19: 100nF; C_0402_1005Metric
NT3: NetTie_2; NetTie-2_SMD_Pad0.5mm
R28: 10k 1%; R_0402_1005Metric
U7: RFM95W-915S2; HOPERF_RFM9XW_SMD; MfgPart RFM95W-915S2

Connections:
+3V3: C18.1, C19.1, R28.1, U7.13 (3.3V); also elsewhere on the board
DIO0: U7.14 (DIO0); also elsewhere on the board
DIO1: U7.15 (DIO1); also elsewhere on the board
GND: NT3.1; also elsewhere on the board
GND_ANT: AE1.2 (Shield), U7.10 (GND)
GND_RADIO: C18.2, C19.2, NT3.2, U7.1 (GND), U7.8 (GND)
MISO: U7.2 (MISO); also elsewhere on the board
MOSI: U7.3 (MOSI); also elsewhere on the board
NSS: R28.2, U7.5 (NSS); also elsewhere on the board
unnamed: AE1.1 (A), U7.9 (ANT)
RESET: U7.6 (RESET); also elsewhere on the board
SCK: U7.4 (SCK); also elsewhere on the board

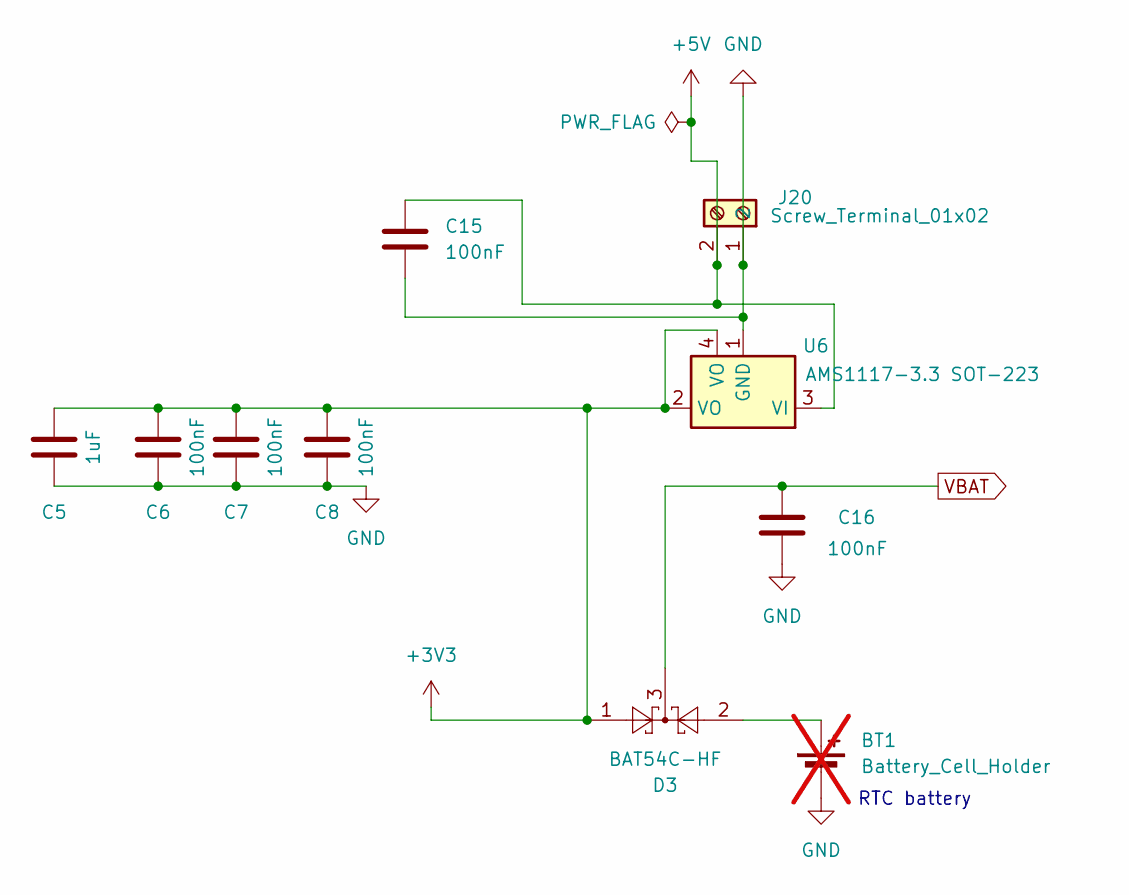
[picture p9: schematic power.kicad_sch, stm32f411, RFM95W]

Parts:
BT1: Battery_Cell_Holder; BatteryHolder_LINX_BAT-HLD-012-SMT; MfgPart BAT-HLD-012-SMT; not fitted
C5: 1uF; C_0402_1005Metric
C6, C7, C8, C15, C16: 100nF; C_0402_1005Metric
D3: BAT54C-HF; SOT-23; MfgPart BAT54C-HF
J20: Screw_Terminal_01x02; TerminalBlock_Phoenix_MPT-0,5-2-2.54_1x02_P2.54mm_Horizontal; MfgPart KF128-2.54-2P
U6: AMS1117-3.3 SOT-223; SOT-223; MfgPart AMS1117-3.3

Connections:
+3V3: C5.1, C6.1, C7.1, C8.1, D3.1, U6.2 (VO), U6.4 (VO); also elsewhere on the board
+5V: C15.1, J20.2, U6.3 (VI)
GND: BT1.2 (-), C5.2, C6.2, C7.2, C8.2, C15.2, C16.2, J20.1, U6.1 (GND); also elsewhere on the board
unnamed: BT1.1 (+), D3.2
VBAT: C16.1, D3.3; also elsewhere on the board

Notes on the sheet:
RTC battery

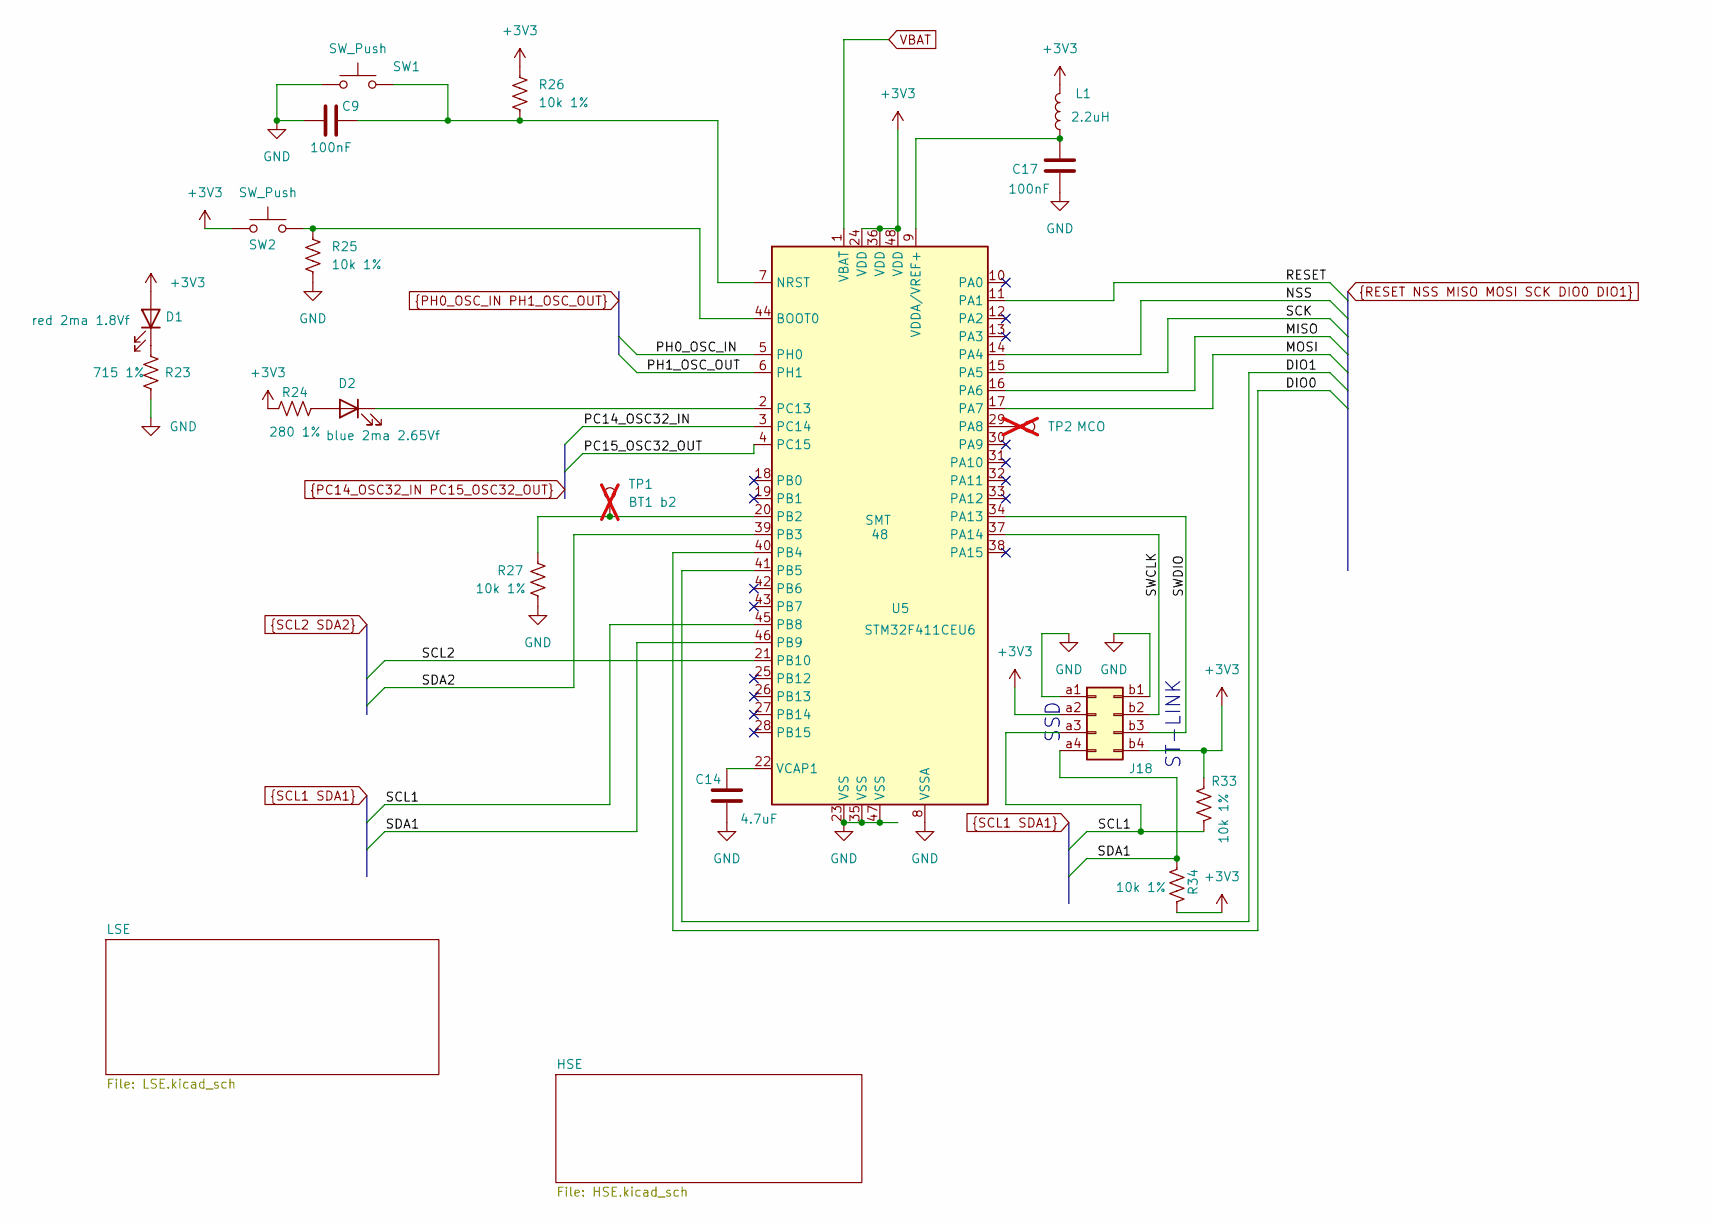
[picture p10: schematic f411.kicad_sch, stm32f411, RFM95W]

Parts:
C9, C17: 100nF; C_0402_1005Metric
C14: 4.7uF; C_0402_1005Metric
D1: red 2ma 1.8Vf; LED_0603_1608Metric; MfgPart APT1608LSECK/J3-PRV
D2: blue 2ma 2.65Vf; LED_0603_1608Metric; MfgPart APT1608LVBC/D
J18: Conn_02x04_Top_Bottom; PinSocket_2x04_P2.54mm_Vertical_SMD; MfgPart HC-PM254-5.0H-2x4PS-02A
L1: 2.2uH; L_0402_1005Metric; MfgPart MLZ1005M2R2WT000
R23: 715 1%; R_0402_1005Metric
R24: 280 1%; R_0402_1005Metric
R25, R26, R27, R33, R34: 10k 1%; R_0402_1005Metric
SW1, SW2: SW_Push; SW_SPST_B3U-1000P; MfgPart B3U-1000P
TP1: BT1 b2; TestPoint_Pad_D1.0mm; not fitted
TP2: MCO; TestPoint_Pad_D1.0mm; not fitted
U5: STM32F411CEU6; QFN-48-1EP_7x7mm_P0.5mm_EP5.6x5.6mm; MfgPart STM32F411CEU6

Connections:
+3V3: D1.2 (A), J18.a2, J18.b4, L1.2, R24.1, R26.1, R33.1, R34.2, SW2.1, U5.24 (VDD), U5.36 (VDD), U5.48 (VDD); also elsewhere on the board
/f411/SWCLK: J18.b2, U5.37 (PA14)
/f411/SWDIO: J18.b3, U5.34 (PA13)
DIO0: U5.40 (PB4); also elsewhere on the board
DIO1: U5.41 (PB5); also elsewhere on the board
GND: C9.1, C14.2, C17.2, J18.a1, J18.b1, R23.2, R25.2, R27.2, SW1.1, U5.8 (VSSA), U5.23 (VSS), U5.35 (VSS), U5.47 (VSS), U5.49 (VSS); also elsewhere on the board
MISO: U5.16 (PA6); also elsewhere on the board
MOSI: U5.17 (PA7); also elsewhere on the board
NSS: U5.14 (PA4); also elsewhere on the board
unnamed: D1.1 (K), R23.1
unnamed: D2.2 (A), R24.2
unnamed: D2.1 (K), U5.2 (PC13)
unnamed: R25.1, SW2.2, U5.44 (BOOT0)
unnamed: C9.2, R26.2, SW1.2, U5.7 (NRST)
unnamed: TP2.1 (1_1), U5.29 (PA8)
unnamed: R27.1, TP1.1 (1_1), U5.20 (PB2)
unnamed: C14.1, U5.22 (VCAP1)
unnamed: C17.1, L1.1, U5.9 (VDDA/VREF+)
PC14_OSC32_IN: U5.3 (PC14); also elsewhere on the board
PC15_OSC32_OUT: U5.4 (PC15); also elsewhere on the board
PH0_OSC_IN: U5.5 (PH0); also elsewhere on the board
PH1_OSC_OUT: U5.6 (PH1); also elsewhere on the board
RESET: U5.11 (PA1); also elsewhere on the board
SCK: U5.15 (PA5); also elsewhere on the board
SCL1: J18.a3, R33.2, U5.45 (PB8)
SCL2: U5.21 (PB10); also elsewhere on the board
SDA1: J18.a4, R34.1, U5.46 (PB9)
SDA2: U5.39 (PB3); also elsewhere on the board
VBAT: U5.1 (VBAT); also elsewhere on the board

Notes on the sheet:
SSD
ST-LINK

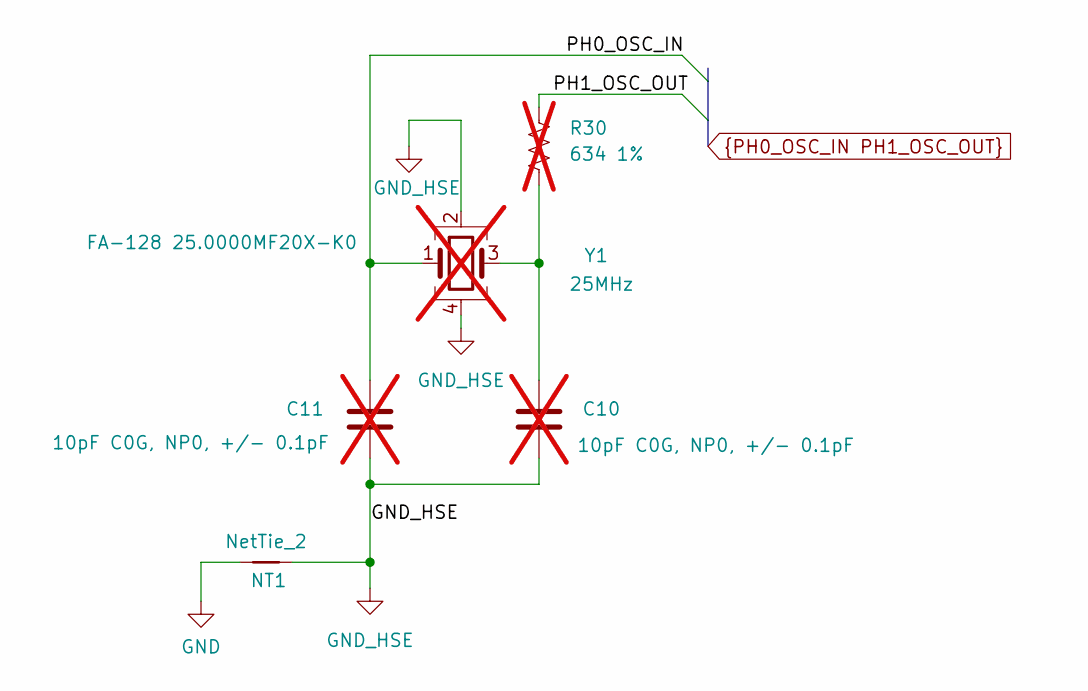
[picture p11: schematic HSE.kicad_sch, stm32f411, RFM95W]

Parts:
C10, C11: 10pF C0G, NP0, +/- 0.1pF; C_0402_1005Metric; not fitted
NT1: NetTie_2; NetTie-2_SMD_Pad0.5mm
R30: 634 1%; R_0402_1005Metric; not fitted
Y1: 25MHz; Crystal_SMD_2016-4Pin_2.0x1.6mm; MfgPart FA-128 25.0000MF20X-K0; not fitted

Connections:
GND: NT1.1; also elsewhere on the board
GND_HSE: C10.1, C11.1, NT1.2, Y1.2, Y1.4
unnamed: C10.2, R30.2, Y1.3
PH0_OSC_IN: C11.2, Y1.1; also elsewhere on the board
PH1_OSC_OUT: R30.1; also elsewhere on the board

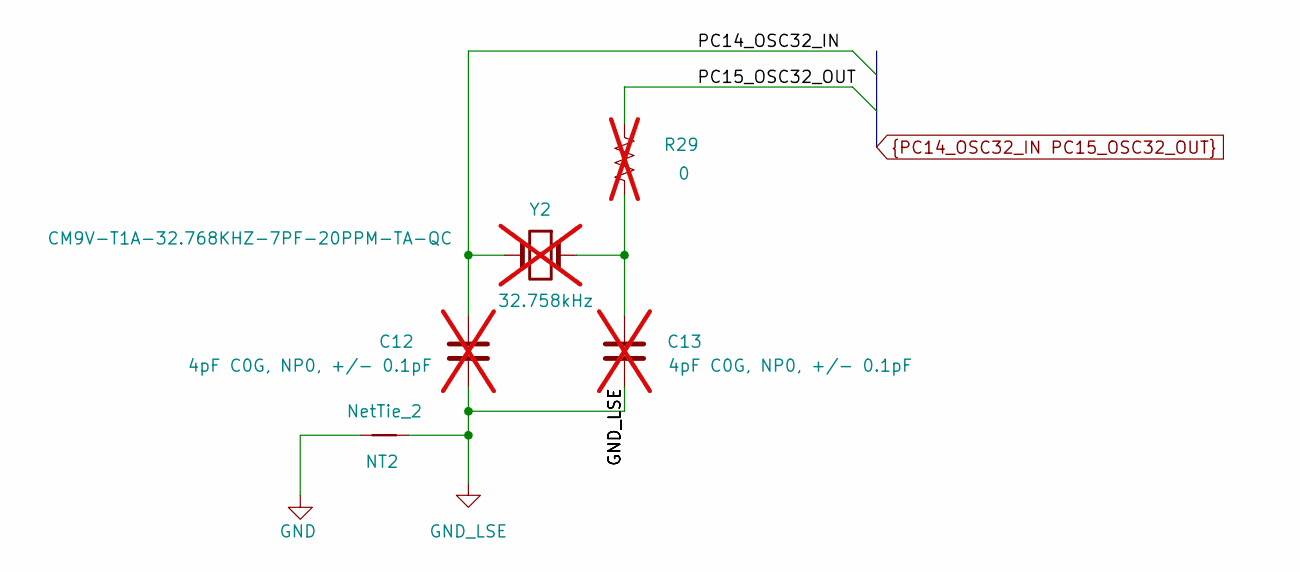
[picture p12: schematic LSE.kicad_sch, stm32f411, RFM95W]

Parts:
C12, C13: 4pF C0G, NP0, +/- 0.1pF; C_0402_1005Metric; not fitted
NT2: NetTie_2; NetTie-2_SMD_Pad0.5mm
R29: 0; R_0402_1005Metric; not fitted
Y2: 32.758kHz; Crystal_SMD_MicroCrystal_CM9V-T1A-2Pin_1.6x1.0mm; MfgPart CM9V-T1A-32.768KHZ-7PF-20PPM-TA-QC; not fitted

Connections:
GND: NT2.1; also elsewhere on the board
GND_LSE: C12.1, C13.1, NT2.2
unnamed: C13.2, R29.2, Y2.1
PC14_OSC32_IN: C12.2, Y2.2; also elsewhere on the board
PC15_OSC32_OUT: R29.1; also elsewhere on the board

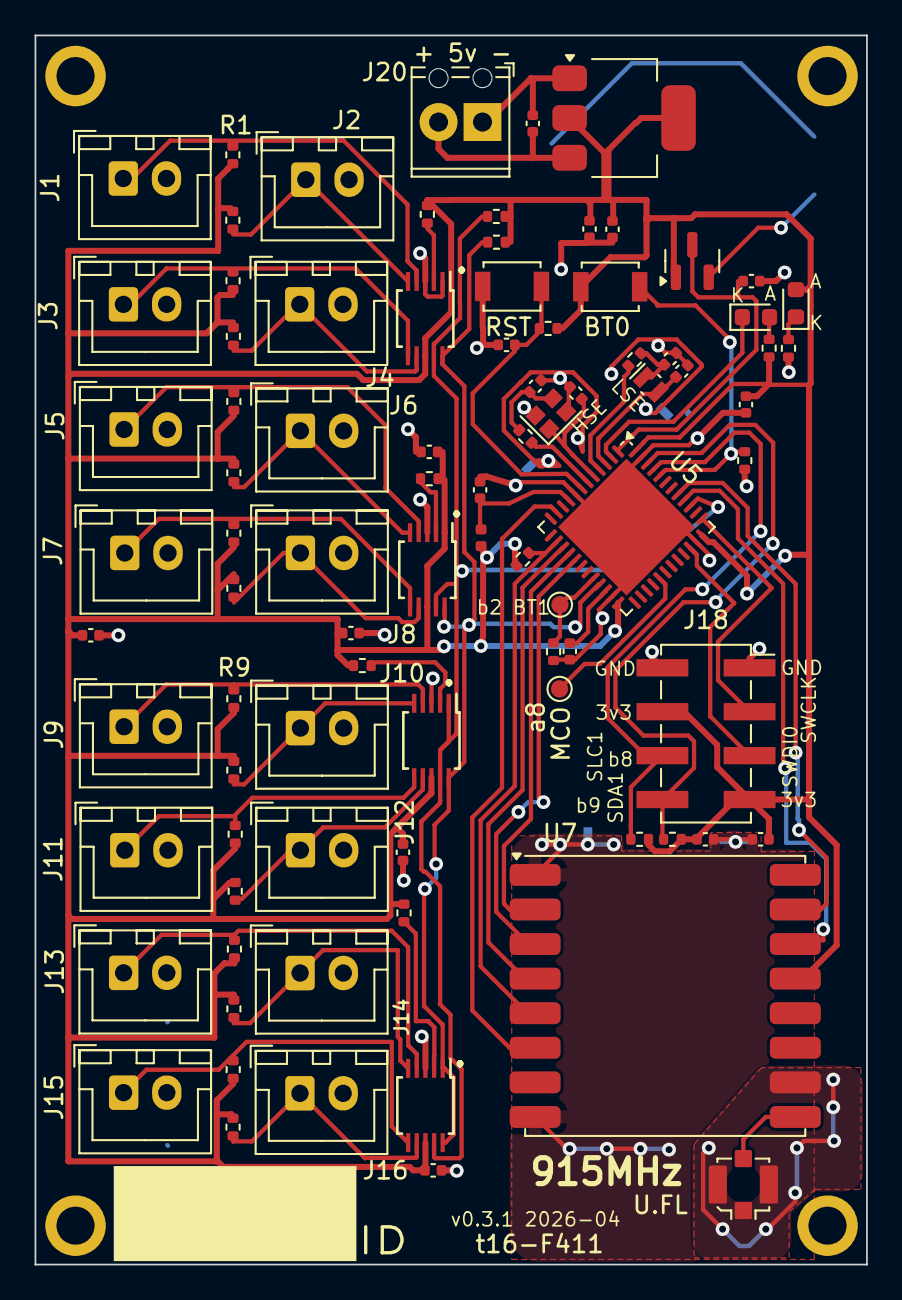
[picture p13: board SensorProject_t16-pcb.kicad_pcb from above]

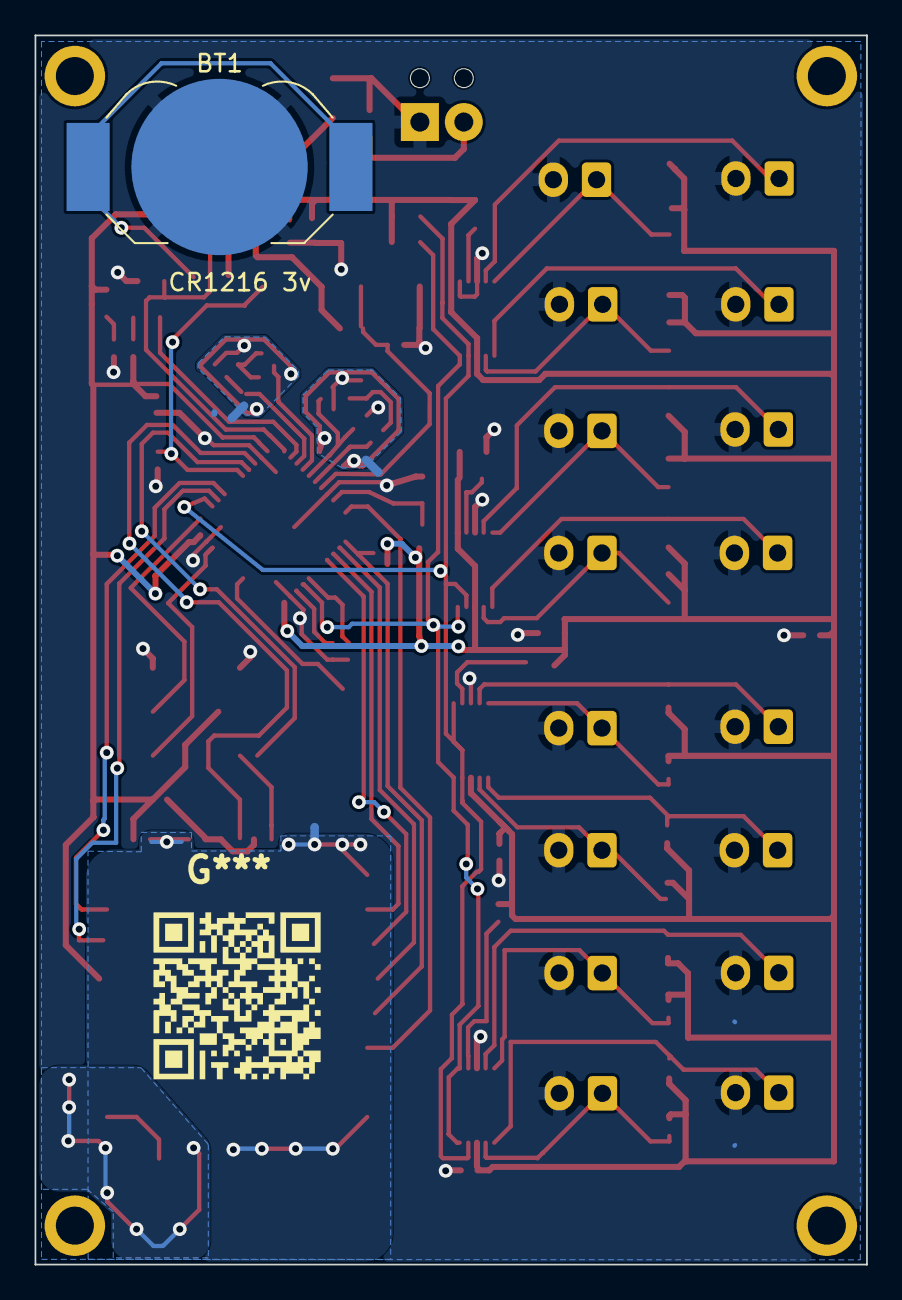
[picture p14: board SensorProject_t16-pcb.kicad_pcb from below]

Board: 2 copper layers, 48.1 x 71.1 mm, 95 parts (4 on the bottom side), 58 nets.

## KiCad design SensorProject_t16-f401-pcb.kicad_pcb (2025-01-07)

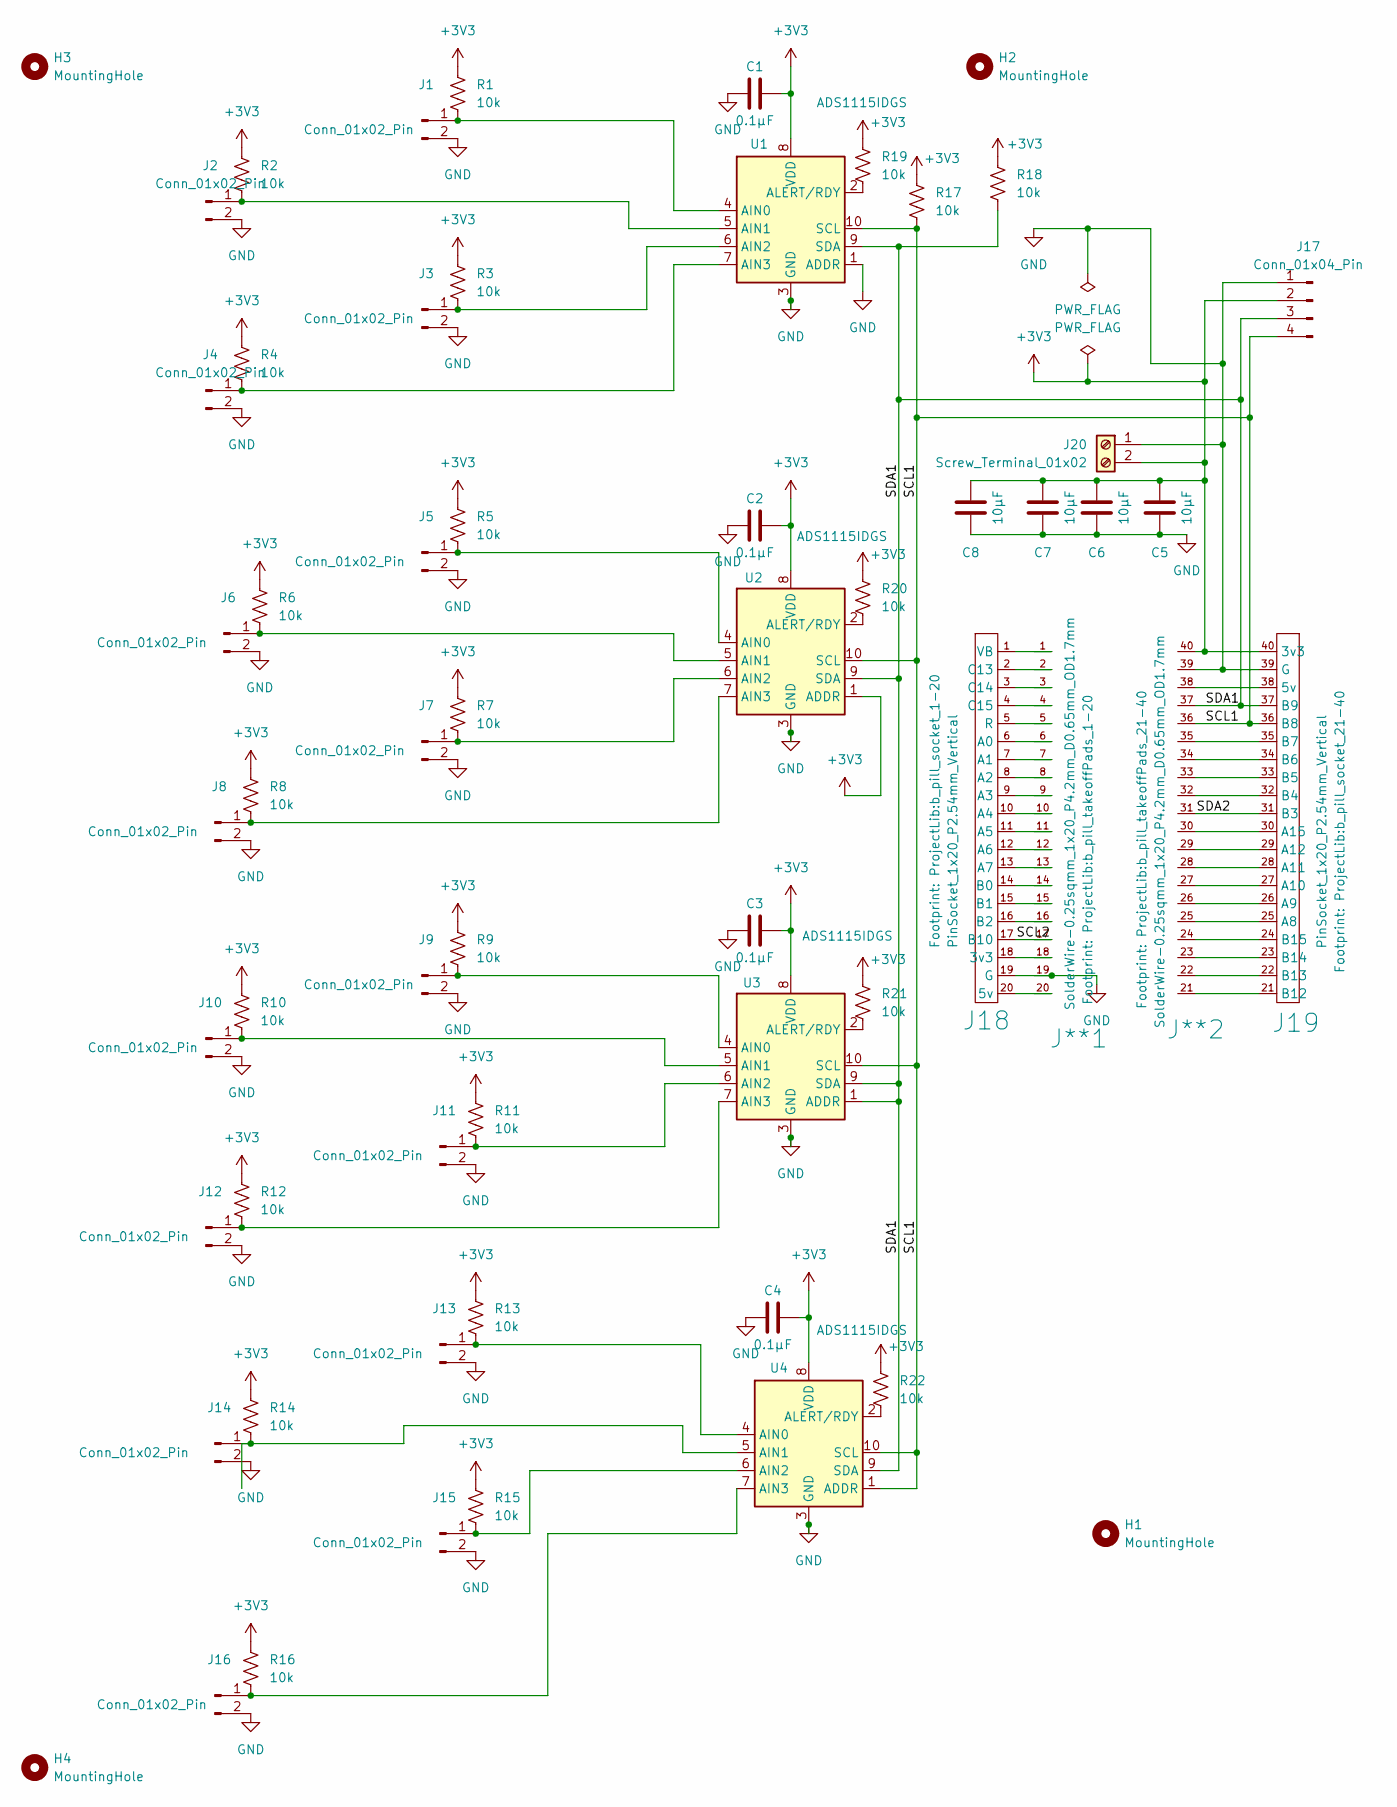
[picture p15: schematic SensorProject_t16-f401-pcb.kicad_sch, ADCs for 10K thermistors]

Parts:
C1, C2, C3, C4: 0.1µF; C_0805_2012Metric
C5, C6, C7, C8: 10µF; C_0805_2012Metric
H1, H2, H3, H4: MountingHole; MountingHole_2.2mm_M2_ISO7380_Pad
J1, J2, J3, J4, J5, J6, J7, J8, J9, J10, J11, J12, J13, J14, J15, J16: Conn_01x02_Pin; JST_XH_B2B-XH-A_1x02_P2.50mm_Vertical
J17: Conn_01x04_Pin; JST_XH_B4B-XH-A_1x04_P2.50mm_Vertical
J18: PinSocket_1x20_P2.54mm_Vertical; b_pill_socket_1-20
J19: PinSocket_1x20_P2.54mm_Vertical; b_pill_socket_21-40
J20: Screw_Terminal_01x02; TerminalBlock_Phoenix_MPT-0,5-2-2.54_1x02_P2.54mm_Horizontal
J**1: SolderWire-0.25sqmm_1x20_P4.2mm_D0.65mm_OD1.7mm; b_pill_takeoffPads_1-20
J**2: SolderWire-0.25sqmm_1x20_P4.2mm_D0.65mm_OD1.7mm; b_pill_takeoffPads_21-40
R1, R2, R3, R4, R5, R6, R7, R8, R9, R10, R11, R12, R13, R14, R15, R16, R17, R18, R19, R20, R21, R22: 10k; R_0603_1608Metric
U1, U2, U3, U4: ADS1115IDGS; TSSOP-10_3x3mm_P0.5mm

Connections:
+3V3: C1.1, C2.1, C3.1, C4.1, C5.1, C6.1, C7.1, C8.1, J17.2, J19.40 (3v3), J20.2, J**2.40, R1.1, R2.1, R3.1, R4.1, R5.1, R6.1, R7.1, R8.1, R9.1, R10.1, R11.1, R12.1, R13.1, R14.1, R15.1, R16.1, R17.1, R18.1, R19.1, R20.1, R21.1, R22.1, U1.8 (VDD), U2.1 (ADDR), U2.8 (VDD), U3.8 (VDD), U4.8 (VDD)
/SCL1: J17.4, J19.36 (B8), J**2.36, R17.2, U1.10 (SCL), U2.10 (SCL), U3.10 (SCL), U4.1 (ADDR), U4.10 (SCL)
/SCL2: J18.17 (B10), J**1.17
/SDA1: J17.3, J19.37 (B9), J**2.37, R18.2, U1.9 (SDA), U2.9 (SDA), U3.1 (ADDR), U3.9 (SDA), U4.9 (SDA)
/SDA2: J19.31 (B3), J**2.31
GND: C1.2, C2.2, C3.2, C4.2, C5.2, C6.2, C7.2, C8.2, J1.2, J2.2, J3.2, J4.2, J5.2, J6.2, J7.2, J8.2, J9.2, J10.2, J11.2, J12.2, J13.2, J14.2, J15.2, J16.2, J17.1, J18.19 (G), J19.39 (G), J20.1, J**1.19, J**2.39, U1.1 (ADDR), U1.3 (GND), U2.3 (GND), U3.3 (GND), U4.3 (GND)
unnamed: J1.1, R1.2, U1.4 (AIN0)
unnamed: J2.1, R2.2, U1.5 (AIN1)
unnamed: J3.1, R3.2, U1.6 (AIN2)
unnamed: J4.1, R4.2, U1.7 (AIN3)
unnamed: J5.1, R5.2, U2.4 (AIN0)
unnamed: J6.1, R6.2, U2.5 (AIN1)
unnamed: J7.1, R7.2, U2.6 (AIN2)
unnamed: J8.1, R8.2, U2.7 (AIN3)
unnamed: J9.1, R9.2, U3.4 (AIN0)
unnamed: J10.1, R10.2, U3.5 (AIN1)
unnamed: J11.1, R11.2, U3.6 (AIN2)
unnamed: J12.1, R12.2, U3.7 (AIN3)
unnamed: J13.1, R13.2, U4.4 (AIN0)
unnamed: J14.1, R14.2, U4.5 (AIN1)
unnamed: J15.1, R15.2, U4.6 (AIN2)
unnamed: J16.1, R16.2, U4.7 (AIN3)
unnamed: J18.18 (3v3), J**1.18
unnamed: J18.20 (5v), J**1.20
unnamed: J18.6 (A0), J**1.6
unnamed: J18.7 (A1), J**1.7
unnamed: J18.8 (A2), J**1.8
unnamed: J18.9 (A3), J**1.9
unnamed: J18.10 (A4), J**1.10
unnamed: J18.11 (A5), J**1.11
unnamed: J18.12 (A6), J**1.12
unnamed: J18.13 (A7), J**1.13
unnamed: J18.14 (B0), J**1.14
unnamed: J18.15 (B1), J**1.15
unnamed: J18.16 (B2), J**1.16
unnamed: J18.2 (C13), J**1.2
unnamed: J18.3 (C14), J**1.3
unnamed: J18.4 (C15), J**1.4
unnamed: J18.5 (R), J**1.5
unnamed: J18.1 (VB), J**1.1
unnamed: J19.38 (5v), J**2.38
unnamed: J19.25 (A8), J**2.25
unnamed: J19.26 (A9), J**2.26
unnamed: J19.27 (A10), J**2.27
unnamed: J19.28 (A11), J**2.28
unnamed: J19.29 (A12), J**2.29
unnamed: J19.30 (A15), J**2.30
unnamed: J19.32 (B4), J**2.32
unnamed: J19.33 (B5), J**2.33
unnamed: J19.34 (B6), J**2.34
unnamed: J19.35 (B7), J**2.35
unnamed: J19.21 (B12), J**2.21
unnamed: J19.22 (B13), J**2.22
unnamed: J19.23 (B14), J**2.23
unnamed: J19.24 (B15), J**2.24
unnamed: R19.2, U1.2 (ALERT/RDY)
unnamed: R20.2, U2.2 (ALERT/RDY)
unnamed: R21.2, U3.2 (ALERT/RDY)
unnamed: R22.2, U4.2 (ALERT/RDY)

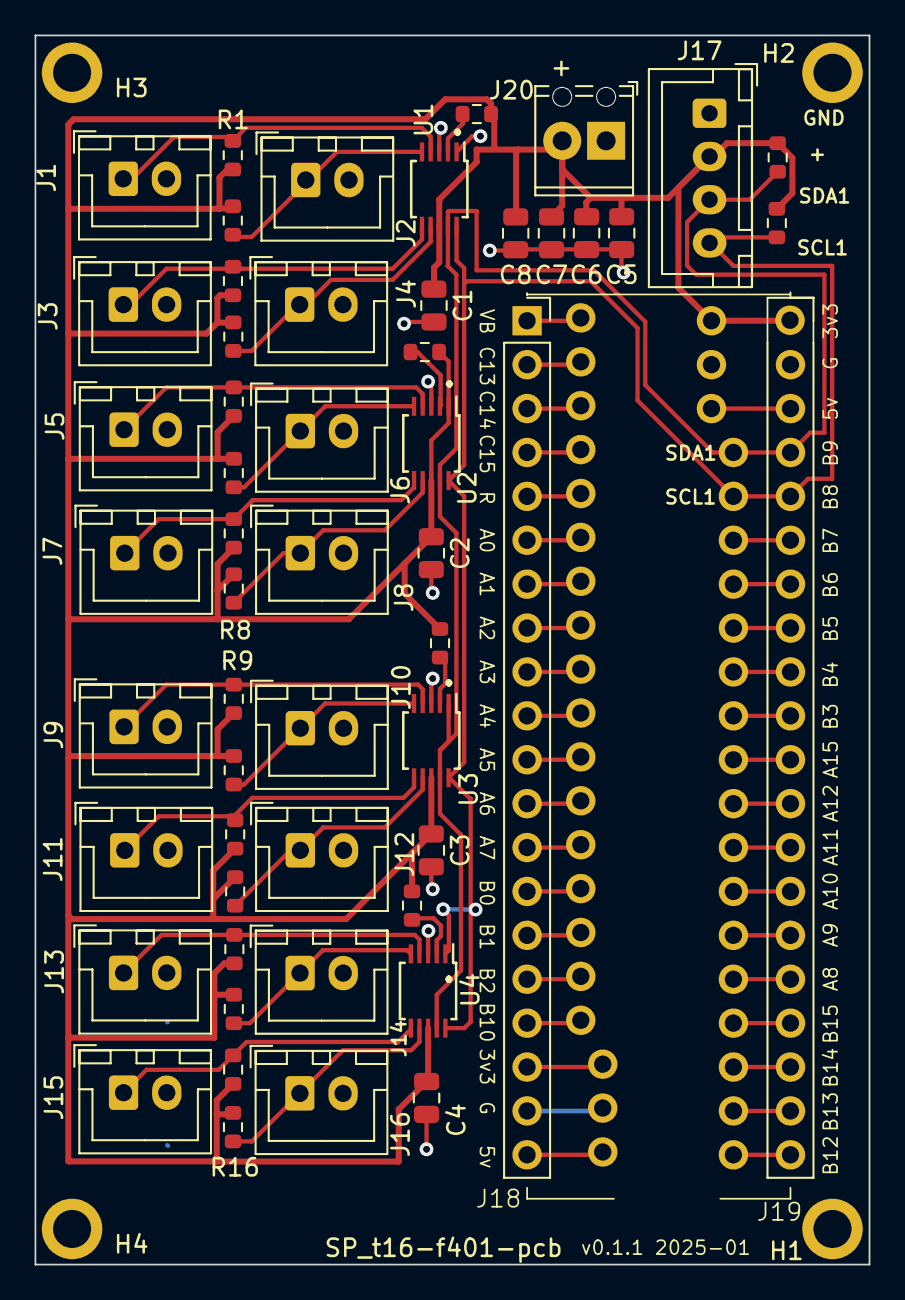
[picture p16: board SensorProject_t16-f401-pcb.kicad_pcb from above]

Board: 2 copper layers, 48.3 x 71.1 mm, 60 parts (0 on the bottom side), 59 nets.

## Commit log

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2023-08-09 initial rough design, v0.0.1
    [ads1115with16JTS.kicad_pcb, ads1115with16JTS.kicad_sch]
2023-08-09 snapshot v0.0.10
    [ads1115with16JTS.kicad_pcb, ads1115with16JTS.kicad_sch]
2023-08-10 changes for v0.0.12
    [ads1115with16JTS.kicad_pcb, ads1115with16JTS.kicad_sch]
2023-08-10 v0.0.14 snapshot.
    [ads1115with16JTS.kicad_pcb, ads1115with16JTS.kicad_sch]
2023-08-11 snapshot v0.1.0-pre
    [ads1115with16JTS.kicad_pcb, ads1115with16JTS.kicad_sch]
2023-08-15 change solder mask for takeoff pads, which will not be soldered.
    [ads1115with16JTS.kicad_pcb, ads1115with16JTS.kicad_sch]
2023-08-16 adjustments to mask and silkscreen.
    [ads1115with16JTS.kicad_pcb]
2023-08-17 moved PG.kicad_sym to ProjectLib.kicad_sym and added all project symbols so project has a complete set of stable symbols.
    [ads1115with16JTS.kicad_pcb, ads1115with16JTS.kicad_sch]
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2023-08-26 footprint lib adjustments.
    [ads1115with16JTS.kicad_pcb, ads1115with16JTS.kicad_sch]
2023-08-29 ongoing cleanup.
    [ads1115with16JTS.kicad_pcb]
2023-09-07 ongoing minor adjustments.
    [ads1115with16JTS.kicad_sch]
2023-09-07 moved connectors J17 and J20 and mounting hole H2 so power wire connection is in a better place.
    [ads1115with16JTS.kicad_pcb]
2023-09-07 added 2 more noise caps on power line. Ongoing attempt to update PCB from schematic and keep footprint links to ProjectLib.
    [ads1115with16JTS.kicad_pcb, ads1115with16JTS.kicad_sch]
2023-09-14 added 2 more power noise caps and changed to 10muF.
    [ads1115with16JTS.kicad_pcb, ads1115with16JTS.kicad_sch]
2023-09-15 sized slightly larger, added 2 more mounting holes.
    [ads1115with16JTS.kicad_pcb, ads1115with16JTS.kicad_sch]
2024-04-18 Footprint adjustments to get tthem all from ProjectLib.pretty. Using Kicad 8.0.1.
    [ads1115with16JTS.kicad_pcb, ads1115with16JTS.kicad_sch]
2024-05-20 Removed test points because there is no room. Trying to sync symbol footprints and pcb footprints.
    [ads1115with16JTS.kicad_pcb, ads1115with16JTS.kicad_sch]
2024-05-20 DRC runs clean.
    [ads1115with16JTS.kicad_pcb, ads1115with16JTS.kicad_sch]
2024-06-02 as first submit to PCBway.
    [ads1115with16JTS.kicad_pcb]
2024-08-15 added pullup on scl, sda. Other ongoing minor adjustments.
    [ads1115with16JTS.kicad_pcb, ads1115with16JTS.kicad_sch]
2024-08-15 fixed solde mask on takeoffPads.
    [ads1115with16JTS.kicad_pcb]
2025-01-06 mv/rename ads1115with16JTS to SensorProject_t16-f401-pcb
    [SensorProject_t16-f401-pcb.kicad_pcb, SensorProject_t16-f401-pcb.kicad_sch]
2025-01-07 added 10k pullups on ads alert/rdy pins.
    [SensorProject_t16-f401-pcb.kicad_pcb, SensorProject_t16-f401-pcb.kicad_sch]
2025-01-07 Adjusted rename for better convention.
    [SensorProject_t16-pcb.kicad_pcb, SensorProject_t16-pcb.kicad_sch]
2025-01-20 adding sheets for power, radio, and f401.
    [RFM95W.kicad_sch, SensorProject_t16-pcb.kicad_sch, f401.kicad_sch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]
2025-02-01 ongoing add MCU and radio.
    [RFM95W.kicad_sch, SensorProject_t16-pcb.kicad_sch, f401.kicad_sch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]
2025-02-08 ERC passing, Crytals not specified. Considering reverse polarity safeguard.
    [RFM95W.kicad_sch, f401.kicad_sch, power.kicad_sch]
2025-02-21 f401.kicad_sch mostly complete other than xtals. Considering switch to f411 for memory, FPU, and generation 2 oscillator that gives better crystal choices.
    [RFM95W.kicad_sch, SensorProject_t16-pcb.kicad_sch, f401.kicad_sch]
2025-03-04 switched to F411. Added sheets for LSE and HSE.
    [HSE.kicad_sch, LSE.kicad_sch, RFM95W.kicad_sch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]
2025-03-20 layout with F411 roughly good but needs work.
    [HSE.kicad_sch, LSE.kicad_sch, RFM95W.kicad_sch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]
2025-03-25 Most routing done but not checked. Moat around HSE but no net-tie yet.
    [HSE.kicad_sch, SensorProject_t16-pcb.kicad_pcb, f411.kicad_sch]
2025-04-01 Moats complete. No errors. Net tie needs better zone and check crystals, BoM, etc. And general review.
    [HSE.kicad_sch, LSE.kicad_sch, SensorProject_t16-pcb.kicad_pcb]
2025-04-12 battery needs work.
    [SensorProject_t16-pcb.kicad_pcb, f411.kicad_sch, power.kicad_sch]
2025-04-13 battery in place. Need HSE xtal spec.
    [SensorProject_t16-pcb.kicad_pcb]
2025-04-28 near complete, DRC good, ERC has a spurious error about ground on Y1.
    [HSE.kicad_sch, LSE.kicad_sch, RFM95W.kicad_sch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]
2025-05-07 cleanup, ready to submit.
    [HSE.kicad_sch, LSE.kicad_sch, RFM95W.kicad_sch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]
2025-08-22 As made, t16-F411 v0.2.0 2025-05, with added notes about needed fixes and results from some testing.
    [HSE.kicad_sch, LSE.kicad_sch, RFM95W.kicad_sch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]
2025-08-27 Most post v0.2.0 fixes done. About to mess with GND_ANT zone and net.
    [HSE.kicad_sch, LSE.kicad_sch, RFM95W.kicad_sch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]
2025-08-28 Added U.FL for antenna, with GND_ANT zone.
    [HSE.kicad_sch, LSE.kicad_sch, RFM95W.kicad_sch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]
2025-08-31 BOM cleaned up.
    [HSE.kicad_sch, LSE.kicad_sch, RFM95W.kicad_sch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]
2025-08-31 added test pad access to PB2 for boot1, renames J18 to TP2.
    [SensorProject_t16-pcb.kicad_pcb, f411.kicad_sch]
2025-09-01 flip side for radio in progress.
    [SensorProject_t16-pcb.kicad_pcb, SensorProject_t16-pcb.kicad_sch, f411.kicad_sch]
2025-09-01 finished flipping radio side.
    [SensorProject_t16-pcb.kicad_pcb, f411.kicad_sch]
2025-09-01 radio flip final cleanup.
    [f411.kicad_sch]
2025-09-01 completed cleanup of v0.2.0 fixes and switch radio side.
    [HSE.kicad_sch, LSE.kicad_sch, RFM95W.kicad_sch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]
2025-09-02 converted R, C, and L to smaller 0402 footprints. Some trace rearranging and cleanup.
    [HSE.kicad_sch, LSE.kicad_sch, RFM95W.kicad_sch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]
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2025-09-05 some (documentation) cleanup while submitting for fabrication.
    [RFM95W.kicad_sch, SensorProject_t16-pcb.kicad_pcb, SensorProject_t16-pcb.kicad_sch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]
2025-10-18 v0.2.2 with BOM fixes, some additional documentation and cleanup.
    [RFM95W.kicad_sch, f411.kicad_sch]
2025-11-29 improved schematic sheet titles.
    [HSE.kicad_sch, LSE.kicad_sch, RFM95W.kicad_sch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]
2026-04-02 minor, pre kicad v10 upgrade.
    [SensorProject_t16-pcb.kicad_pcb]
2026-04-05 added new battery holder footprint.
    [HSE.kicad_sch, LSE.kicad_sch, RFM95W.kicad_sch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]
2026-04-10 added gnd-radio and gnd-ant zones on two layers. ERC and DRC mostly good. (Two warnings about pads field in NetTie footprints.)
    [HSE.kicad_sch, LSE.kicad_sch, RFM95W.kicad_sch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]
2026-04-10 added caps to radio_gnd.
    [RFM95W.kicad_sch, SensorProject_t16-pcb.kicad_pcb, SensorProject_t16-pcb.kicad_sch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]
2026-04-11 added ID white space and QR code.
    [SensorProject_t16-pcb.kicad_pcb]
2026-04-11 3dmodels converted from .wrl to .step because .wrl seem to be missing in kicad 10.
    [SensorProject_t16-pcb.kicad_pcb]
2026-04-12 Cleaned up v0.3.0 2026-04. LSE and HSE populated.
    [RFM95W.kicad_sch, SensorProject_t16-pcb.kicad_pcb, SensorProject_t16-pcb.kicad_sch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]
2026-04-13 added QR and ID blocks on silkscreen. Marked HSE and LSE as DNP. Revised version number to 0.3.1.
    [HSE.kicad_sch, LSE.kicad_sch, RFM95W.kicad_sch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]
